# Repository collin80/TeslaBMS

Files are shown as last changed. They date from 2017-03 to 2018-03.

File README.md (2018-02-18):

Arduino compatible project to interface with the BMS slave 
board on Tesla Model S modules.

The modules are daisy-chained together with a TTL interface.
The interface uses a Molex 15-97-5101 connector and runs at
612500 baud. This can be a difficult baud rate to match with
arduino compatible processors. The Arduino Due and Teensy
3.5/3.6 boards are confirmed to be able to generate a suitably
close baud rate. The factory wiring to each module is comprised
of two sets of 5 differently colored wires:

* Red = 5V input to the module
* Green = Gnd for power and signal
* Gray = Fault output
* Yellow = UART Wire
* Blue = UART Wire

The fault output is active low. Use your own pull up to the fault line and if the line is pulled low then a fault has occurred.

Here is a PDF that explains how the wiring between modules and the master board is supposed to be:
https://cdn.hackaday.io/files/10098432032832/wiring.pdf

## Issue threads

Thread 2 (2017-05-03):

EEProm settings

tomdebree, 2017-05-03:
I need to rewrite the serial console to remove the references to the EEProm library because it is not part of a teensy. But great libraries so far, will see about now creating a bms master based on these libraries.

tomdebree, 2017-05-03:
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

collin80, 2017-05-03:
I had previously ported the GVRET firmware to Teensy so I ran into this same situation. The Teensy does have EEPROM it's just a different library. You can look at https://github.com/collin80/TeensyRET to see what I did.

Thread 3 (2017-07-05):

We are building a Tesla Powered car

jjwallace, 2017-07-05:
Hello, we are building an electric power car.  Which other boards have you tested on?  What would you suggest for a high-quality board?  I want to try interfacing with Tesla batteries this next week.

collin80, 2017-07-07:
Well, I've tested using an Arduino Due and a Teensy 3.6. I don't have experience outside those too. I did test a breadboard design with both of them so a purpose built board is not 100% necessary, just nice to have. There are a few things to keep in mind when searching for a solution to interface to the Tesla BMS sub-boards:

1. They're 5V so if you use a 2.5 or 3.3v board you will need level shifters. Both boards I used are 3.3v so I used logic AND gates as level buffers.
2. The baud rate is 612500. Slow processors will either not be able to generate this high of a baud rate or will not be able to generate this exact baud rate properly. 612500 does not exactly divide into the clock rate of most processors. The processor on the Tesla main board is 24.5MHz which is how they generate such a screwy rate. Both the Due and Teensy can generate a suitably close baud rate. The Due has an 84Mhz clock and 84Mhz / 137 = 613138 baud which is close enough to work. Some processors do not have such free baud divisors. Technically 16Mhz / 26 would probably work though.
3. A thousand amps tends to generate a lot of EMF so even if you didn't need logic buffers you might be best off using them as well as inductors and other noise cancelling devices. Battery packs are a noisy place to store electronics.

jjwallace, 2017-07-18:
Very interesting, this is great!

jorakarandas, 2017-10-23:
Hey Collin! Thanks for your contribution to the community! All the diy-ers appreciate it a lot.

 I encountered an issue with the Arduino Due and the Tesla BMS rev 2 and rev 3 boards. Arduino is sending the messages, but the boards don't respond back (from hardware point of view everything is fine, added lvl shifters).  Have tried 1 by 1 about 7 boards and another 8 which I installed in my car already in a daisy chain configuration as described by you.

What problems have you encountered during set up phase? Did the config work right out of the box? Was anything necessary from your side to make it work?
Thank you!!
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

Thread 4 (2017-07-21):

Jumping voltage Measurements

tomdebree, 2017-07-21:
I am currently working on using the data read from the slave to control charging I noticed there is quite a jump in values. The jumps are around 0.05V, currently using a high level timer to reset once a certain threshold is past.
Collin, did you notice the jumping of values too or is it possible to introduce a smoothing function over the values per cell?

collin80, 2017-07-23:
The resolution of the readings is a lot finer than 0.05v but if you're talking about full pack voltage then I suppose it is possible that 12 cells in series could add up to that much fluctuation. I hadn't noticed a constant 0.05 fluctuation but I suppose it does seem like the value wanders around a little bit.  It's certainly possible to introduce a layer of smoothing over the values. You could, for instance, take the previous 10 readings and average them. If you do this every 1 second then you'll get an average over the past 10 seconds. That might be OK for what you're doing or it might not. You can always read more rapidly and then average. If you need a 1 second value then you could read 8 per second and average over the 8. I don't know that such a thing will get added to this code base as it is meant mostly as a starting point for other projects and not as the absolute final code.

tomdebree, 2017-07-23:
I am using the commands:
bms.getAllVoltTemp();
bms.printPackDetails();

The values which are jumping are the cell voltages. these get put out roughly every 550ms

Attached a log from running these, all be it with some extra code to control charging.
         
[Tesla BMS voltage log.txt](https://github.com/collin80/TeslaBMS/files/1168440/Tesla.BMS.voltage.log.txt)

collin80, 2017-07-23:
Yes, I'm seeing it in your logs. It does appear to be about 0.05v. I'm thinking that it must be coming directly from the Tesla BMS module. I'd guess that their master board averages the voltages over multiple readings to make it more steady. Apparently the same thing will have to happen here. Sample more quickly and average the result. I'll try to do some more testing of this as well.

tomdebree, 2017-07-23:
If you can let me know how steady your readings are, I want to be sure it is not a wiring issue or something like that on my end.

collin80, 2017-07-25:
My readings are stable to within about 4 millivolts which seems to be a lot more stability that you're seeing.
I've attached a log from my pack. You can see that it sometimes fluctuates a little but, in general, readings are more stable than you're seeing. Perhaps your voltage source is shaky or you're picking up noise or your BMS modules are damaged. I can't tell for sure. But, hopefully having this baseline log file helps.

[TeslaBMS_Log.txt](https://github.com/collin80/TeslaBMS/files/1171632/TeslaBMS_Log.txt)

tomdebree, 2017-07-25:
Could you please test with turning the balancing function on?

tomdebree, 2017-07-25:
I can confirm it is indeed due to the balancing. Time to add another state to my state machine then.

Closed 2017-07-25.

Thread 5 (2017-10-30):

Tesla BMS reverse engineering

Pagode, 2017-10-30:
Hello collin80,

I am currently trying to connect Arduino Due with one Tesla Battery Package as part of a project for my study.
The Arduino is sending its messages but can't find the Tesla board.
I am also not sure how to wire the fault output you described in your hackaday project.
Hopefully you can give me any advice so that I can get further.

I am looking forward to hearing from you!

Reply:
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

Wiring:
red = 5V (Pin 1)
green = Ground (Pin 3)
yellow = TX (Pin 2)
white = RX (Pin 9)
black = fault (Pin 6)
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

jorakarandas, 2017-10-30:
Hi Pagode,

You shouldnt connect directly the boards to arduino due. Grab a 5v to 3.3v
level shifter, like 74ahc1g08.

Tell us your progress after that.

Good luck,
J

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

danfador, 2018-06-10:
Hello, @jorakarandas do you succeeded with tesla BMS and Arduino, I have two model s module and I get an Arduino Due  + Molex connector, what else I have to boy to comunicate with Tesla BMS?

One more question, without any external connection does testa BMS balance the cells ore not?

Thank you!

bstarr119, 2018-07-10:
Good Evening All,

I am having similar troubles as the original poster, unfortunately I cannot upload pictures from the mobile site. I have incorporated a level shifter with the due so that I do not over volt the tx rx ports. I will need to figure out something new to try but I am running low on ideas as I am new to CANbus and due ^^

NiallDarwin, 2019-08-21:
Hi @jorakarandas thanks for your suggestion of the level shifter. Please can you read this and let me know if I've understood correctly:
The ESP32 is a 3.3V chip & board so 5V could damage it.
The Tesla BMS boards are 5V.
This means that the Tesla board's Tx & Rx will be running at (up to) 5V and can therefore damage the ESP32. So using a level shifter means you can transmit the signal but drop voltage.
If all this is right I've got another question: Does the shifter cope with the baud rate OK? Is this a specification I need to look for when choosing a board?
Thank you :)

collin80, 2019-08-21:
Yes, the Tesla hardware runs at 5V but an Arduino Due or an ESP32 run at 3.3v instead. So you need a level shifter to go back and forth between the two voltage levels. What you need is a level shifter that can go fast enough. You have the baud rate of the Tesla hardware (625000) so what you need is a level shifter that can handle 1MHz digital signals. Cheaper shifters probably won't. But, plenty of options exist. And, in a pinch perhaps you've already got AND logic chips. Just feed the input to both inputs to the AND gate and output at the proper voltage. Logic gate chips tend to be plenty fast enough. You just have to make sure that the chips you're using will trigger at 3.3 and 5v even if the inputs are technically higher in voltage than the V+ rail on the chip.

NiallDarwin, 2019-08-21:
Thank you.

On Thu, Aug 22, 2019 at 11:07 AM Collin Kidder <notifications@github.com>
wrote:

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

--
Niall
NZ cell +64 221 275 438

NiallDarwin, 2019-08-24:
So I've now got  bi-directional board very like [this sparkfun offering](https://learn.sparkfun.com/tutorials/bi-directional-logic-level-converter-hookup-guide/all) and have made something happen. Unfortunately it seems I'm only transmitting not receiving-see screenshot. Two things I'm not sure of* are:
1/ I'm getting my 5V from the 5V pin of the Due. It's getting it from my laptop. My meter shows about 4.9V which I'd expect to be enough. Thoughts?
2/ Does the shifter need any pull up/down on any of the inputs or outputs?
If you want to see the rig, [here's a little video](https://youtu.be/c_d3D_629mw).
Thanks :)
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
*Lots actually but these are the relevant ones ;)

wizkid057, 2019-08-29:
Was linked here by a friend.  I haven't really followed this project, as I developed my own software/hardware to run the BMBs quite a while back (I actually just reflash the 8051 using Tesla's own update protocol, reverse engineered, and run my own code there.)

Anyway, the digital isolator used between the BMS side and the external connector can operate at 2.5V to 5.5V... and can essentially act as a level shifter on its own.  Just power the external side from whatever voltage in that range would be useful to you.  The filtering before the isolator is geared towards 5V operation, and this is the voltage Tesla uses for the bus... but definitely not a solid requirement.  It'll give a few tenths of a volt loss most likely, but shouldn't drop things below the 2.5V minimum at 3.3V supply.

In fact, I'm actually currently running my own home setup with 36 of these in a chain, and it's running at 3.3V directly off of my board's 3.3V regulator (repurposed the board from another project... will eventually use 5V).  Realtime view: https://wk057.solar/bms.php

All of that said, I'm unsure what the benefit of level shifter would be exactly, unless the 3.3V rail isn't strong enough to provide the few mA per board needed to run the isolators.  You should just be able to power the whole thing from 3.3V and be done with it.  The BMB won't know any differently, since the isolated side is still powered by 5V.

collin80, 2019-08-29:
I'm sure you're right. We never investigated the situation that much. We saw that the Tesla main board uses 5v so we kept using that voltage and just added cheap AND gates to shift the signal level. But, it's good to know that this is not strictly necessary. So I suppose everyone else might as well just plain power it with 3.3v and be done.

BobbyBleacher, 2019-08-29:
Well, Niall is getting more than me out of it. When I start up it tells me starting up and factory settings reset, but how do I actually retrieve any useful data now that I'm connected?

BobbyBleacher, 2019-09-01:
Disregard, I've got this all connected, powered up, and operating.,The boards just aren't being recognized by the Due for some reason. I've tried the tx/rx pins as well as the cantx/rx with no success.

KeithMcdorman, 2019-09-02:
Worth noting that if you hooked up the due to 5v signals your signal pins may be toast. The due is not 5v tolerant. Been there done that.

BobbyBleacher, 2019-09-02:
Signal pins are still outputting 3.3v

NiallDarwin, 2019-09-21:
Alrighty, I made it work!
IT WORKS :)
The problem was simple. I was using the wrong serial pins on the Arduino. If you look closely there's three TX/RX ports. I'd gone in on the 0 pair but the board was using the 1s. Hopefully this helps.
We also found that as per lots of advice here the Tesla boards work fine on the 3.3V of the Arduino so no need for the level shifter.
To diagnose this a friend came over and brought his logic analyser. This enabled us to see what the various channels were doing and was much, much better than just blindly trying different leads in different pins. They're NZ$18 here in NZ so probably about US$10 and worth at least 100x more!

Summary of what works for me on my 2016 BMS boards:
Run Tesla boards on 3.3V from Arduino
Use RX1/TX1 pins
No need for level shifter
Baud Rate: 631578 (Haven't tried if this is necessarily the only one but it does work for me)

Thanks Collin for writing and informally supporting this stuff. Thanks everyone else for their support.
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
NiallDarwin, 2019-09-25:
I reckon this can be marked as closed now?

sogorman, 2019-09-28:
Wk057 (been following your work for a while, have chatted with you a few times ago about 5 years ago, big fan), @collin80 , and @NiallDarwin thanks for all the hard work on this project. I am trying to get my arduino to interface with the Tesla BMS and have not had much luck. I have tried running at both 612500 and 617647 baud rate with no response from the board.

I took @wizkid057 advice and am running the board at 3.3V off the arduino header as to not require level shifting on the serial bus.

One question for the three of you.... does the board need to be powered by the pack as well? not sure if the 6S leads from the cells power and subsystem on the module.

I added some debug code to the setup function but here is all I am getting in the serial debugger.

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

I am using Serial1 in config.h and the BMS is connected to RX1, and TX1 on the arduino.

Here are some pics of my test bench...

Anything jump out at you guys?

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

collin80, 2019-09-28:
As WK057 said, the power you give the board is powering the isolation chip. So, you can power that chip with 3.3 or 5v but it was meant for 5V so it probably works best with 5V if you can swing it. But, the BMS side is powered by the cells themselves. Ordinarily the current draw is quite low and everything wakes up when you send it traffic. But, you do need power at the cells in order for the 8051 processor and BMS chip to operate. So, that is your biggest hurdle.

NiallDarwin, 2019-09-29:
@sogorman Yes, the boards need to get power from the Tesla batteries. I've edited my summary above to include this important piece of info. You didn't miss it previously ;)

sogorman, 2019-10-03:
@NiallDarwin appreciate it and thanks to the entire group... she is now talking!

Nzo-Po1, 2023-07-04:
Bonjour @collin80 ,
J'ai besoin de ton aide concernant le code que tu utilises afin d'afficher la tension et la température du pack de batterie. En effet, j'utilise comme support la carte arduino DUE R3 qui fonctionne en 3,3V. Voila le code que j'utilise :
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

Mes principales questions porte surtout sur le code car je ne sais pas où trouver la bilbliothèque SerialConsole.h. Je n'ai pas un niveau élevé en programmation mais il semble que ce soit une bibliothèque que tu ai fais toi même. Sais-tu où puis-je la trouver et comment l'ajouter aux bibliothèques de la carte ?
De plus, je ne comprends pas comment faire fonctionner cette ligne : SerialSpecialInit(USART0, 612500).
Suis-je censé ajouter une bibliothèque ou bien rajouter autre chose ? Pour être honnête, je ne sais pas à quoi corespond non plus les fonctions que tu as écrites comme "BMSModuleManager.h" ou bien "Logger.h". Tu les a écris en JAVA mais la carte Arduino n'et programmable qu'en C++ il me semble, c'est pourquoi je me sens un peu perdu :(

De plus, voici le câblage effectué, j'ai suivi les instructions que tu avais donné.
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

Merci d'avance de ton aide précieuse. ;)

collin80, 2023-07-05:
Well, of all the languages I can read, French is not one! ;) But, thankfully Google Translate exists. I believe you haven't properly downloaded all of the source code for TeslaBMS. The function "SerialSpecialInit" is found right in TeslaBMS.ino up near the top. The SerialConsole and other missing files are also right here in the repo so try downloading it all again. Lastly, make sure you have selected Arduino Due (Native Port) as the board you are compiling for. It's really easy to accidentally try to compile for a different board but this will not work.

Nzo-Po1, 2023-07-06:
Sorry @collin80, I forgot to translate ;) Indeed, I saw that I forgot to download all the libraries I need like due_can, wireEEprom ... So for now, the code compiles fine but I don't have the text in the serial monitor that I'm supposed to have ... Do you think you know why? I'll keep looking.
Anyway, thanks for your work, it helps me a lot :+1:

kveksen, 2023-09-23:
The tesla moduleboard is blinking but I just got this and nothing more.
What did I do wrong?

13:42:34.530 -> Starting up!
13:42:34.530 -> Started serial interface to BMS.
13:42:35.832 -> Resetting to factory defaults

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

Vistr169, 2025-01-24:
Hello @collin80,
Thank you so much for this programm, it work very well for old types of Tesla Batteries.
One question. Is it possible to make some changes at this code, that it work correct with Tesla Batteries 75kw, 100kw 2016-2021?
We had Tesla Model S Long Range 2021 with broken battery. Programm comunicate with BMB but not correct, and commands not the same.

evcepi, 2025-03-18:
Hi Enginers
i have problem with programing Arunio Due
somebody want help me private i pay for help?
I need to programing i need tool for see voltage cells and everthing?
Thank you

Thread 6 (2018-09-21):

closing the main contactors inside the Tesla model-S battpack

TLS1000, 2018-09-21:
Hi, I'm trying to use the kit from EVTV, for using the complete model-S battery 'as is' without opening it.
Your code does a great job reading all cell voltages and so. BUT: the main internal contactors that connect the internal batteries to the power port of the pack don't want to close. Are these main contactors controlled via code or is it purely hardware?

collin80, 2018-09-25:
You'll have to ask Jack directly about that. I wasn't really involved in the whole pack control system. This project you've submitted the issue to is for controlling the modules inside the pack directly.

TLS1000, 2018-09-25:
hmm...the collaboration with Jack is not working out :-) . We will try the kit on a second model-S battery to be sure, but I'm afraid we'll have to take the battery apart and go for 48V-setup.

Closed 2018-09-25.

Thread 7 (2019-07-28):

ESP32 due code

martiinezz, 2019-07-28:
Collin - great work with the code. My question is if you're going to port this code to the latest ESP32 based board?

Thanks.

BobbyBleacher, 2019-09-16:
Is that why none of us can get this working? We've got a newer version of the board this was written for?

collin80, 2019-09-16:
Well, I did in fact port it over to the ESP32 for a project but that project didn't actually end up open source so it isn't on here. But, rest assured, it can work on an ESP32. I think really the biggest change to compile on an ESP32 is that it has no USB based serial so all the status output needs to go to a normal serial port instead and the serial port to communicate with the BMS slaves is initialized differently.

Here's some quick advice for setting up the serial port to the tesla hardware:
HardwareSerial Serial2(1); //define second serial port for Tesla BMS board
Serial2.begin(BMS_BAUD, SERIAL_8N1, 4, 2); //rx pin is 4, tx pin is 2

Obviously BMS_BAUD should be one of the speeds, 612500 being a common one. There's a slightly faster one for newer Tesla hardware, 631578. I think we had better luck just using 631578 all the time. I don't think the ESP32 can quite generate that exact rate but it gets close enough.

So, no, I don't believe the ESP32 is available anywhere but really you just redirect all serial console output to Serial and all BMS traffic to Serial2 - initialized as above.

BobbyBleacher, 2019-09-17:
I'm staring at this code trying to figure out how to make it do just that. I'm mostly unfamiliar with all of this, so most of what I'm trying results in failure to compile or something I don't even want to go try after it does compile because it simply doesn't make sense.

So the Due, which does have SerialUSB, needs to NOT use that and initialize two separate serials (looks like HardwareSerial doesn't need the initialization code you put there), and the Serial2.begin statement provided has two too many arguments.

 What was this originally written for if not the Due?

collin80, 2019-09-17:
No, the code as provided should have worked on the Due. That's what it was written for. I was talking about the ESP32. In order to compile for ESP32 you need the special serial init I posted and you can't use SerialUSB since ESP32 has no SerialUSB - Due does.

BobbyBleacher, 2019-09-17:
Oh... Yes, it definitely doesn't work on the Due as noted in Niall's video. I'm getting the same results as him. LPG on the Tesla forums also had the same experience.
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

collin80, 2019-09-17:
What is interesting about your picture is that you are getting the exact same bytes returning as you sent. That isn't really what it should be doing. The Tesla module should be catching the bytes that you send and be broadcasting but with changes. 7F is a broadcast and 0 if I remember correctly is used to number the modules automatically. It shouldn't be directly passing those bytes back. Something seems odd there. You should make sure you don't have a direct loop between TX and RX. Does your first tesla module in line have LEDs flashing on the board when it gets traffic? Near the bottom you should see flashing upon traffic. This can help to verify that it is receiving data bytes.

BobbyBleacher, 2019-09-17:
The light on the BMB comes on only during power up, but that's it. If you're interested in troubleshooting (and I definitely am) we can chat elsewhere. I have Whatsapp, discord, slack, etc.

collin80, 2019-09-17:
Yeah, sounds like you've got some major comm issues then. Every single time the code tries to send something to the Tesla modules you should get a flash of light at the LED. So, things are not getting through properly. I have slack and I think discord. We can move this out of the github issues and to email, then perhaps to one of the other services from there. kidderc at google's email service.

CZal, 2019-09-17:
Code works for me... I think there is an issue with your wiring to the modules....

Btw, Great work Colin...

BobbyBleacher, 2019-09-17:
Care to share some knowledge? There are several of us that can't get it working and it does not appear to be the wiring. Would love to see photos/videos of your setup.

martiinezz, 2020-01-19:
@BobbyBleacher So what was your issue?

twanek, 2021-02-19:
hello!

thank you sharing this great work! i also would like to port this code to esp32. anyone can help me, where to start? unfortunately, i do not have a due, so i have to begin directly with the esp32...

best regards!

collin80, 2021-02-24:
I gave the relevant advice up above. I don't know for sure what else you'd want to know. On the ESP32 your user facing output should be sent to Serial instead of SerialUSB and you need to initialize the second serial port that talks to the modules as I specified above. Other than that, both chips support Arduino so once you install the Arduino support for ESP32 you should only have to make those two changes and it should work.

MohamedGaberZidan, 2022-12-05:
> I gave the relevant advice up above. I don't know for sure what else you'd want to know. On the ESP32 your user facing output should be sent to Serial instead of SerialUSB and you need to initialize the second serial port that talks to the modules as I specified above. Other than that, both chips support Arduino so once you install the Arduino support for ESP32 you should only have to make those two changes and it should work.

Hello,
when I did this I had some problems with due wire library, could you tell me what I should do?. Thanks in advance.
best regards.

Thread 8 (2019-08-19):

balancing?

Energyfuzzi, 2019-08-19:
Hi, great job!
I try to implement it on a Volkswagen Beetle with 5 Tesla Bricks, looks good!
While checking the balancing, I found that there is something strange inside your code:
You start balancing at 3.9V, and stop when the cellVoltage is below this Voltage minus a balancing hysteresis.
There are 2 problems I see, because "balancing(i)" seems to mean: burn the energy at the resistors at cell(i)!
1) So the Resistors from each cell burn energy every time the Voltage is higher than 3.9 V unless it is below 3.86V, even if the voltage should be at 4.1V.
2) During balancing the Voltagemeasurement does not work properly, because of the structure of the electronic.

I would suggest starting balancing, if the difference to the neighbour cell is to high, maybe via the difference between avgCellVoltage and cellVoltage(i), or just by comparing, and a minimum voltage is guaranteed (as already done).
Then the balancing should last 2-5 min, should stop, then after a short time start the measurement and the balancing again.
What do you think?

collin80, 2019-08-20:
You're pretty much right all the way around. The balancing stuff found in the public code is only to be used as an example of how one might be able to turn on balancing. It certainly isn't a very good algorithm. So, yes, I would recommend you implement something better.

Energyfuzzi, 2019-08-20:
thanks, I´ll change it for my needs on the Volkswagen beetle.
And by the way: thanks once more for finding out, how to communicate with the original TeslaBrickElectronic. It really helps to use the original Brick instead of using a custom BMS!
Has there been something new about the communication in the last 1-2 years (since you posted the code?) All the best from Austria!

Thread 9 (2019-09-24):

BMS board revisions? What should I look for?

baysinger, 2019-09-24:
If I were to purchase a module, is there any particular BMS revisions I should look for? Or are all the Model S modules compatible with this project?

baysinger, 2019-10-18:
To partially answer my own question, it does indeed work with whatever this is:

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

collin80, 2019-10-18:
Sorry, I meant to answer this long ago but completely forgot about it. Any of the Model S battery revisions should work. It appeared that they changed serial speed between revisions but only slightly and the code can support both. To my knowledge there are two main revisions of the BMS boards. One is larger than the other. But, either way they speak the same protocol and the only communication difference is a slight speed change. The old ones were 612500 and the new one something like 631000 (don't remember exactly). Other than that they work the same.

baysinger, 2019-10-22:
Thanks. BTW, I left the baud rate alone (617647) and it's working fine. Not sure where that number comes from, though. Close enough to either speed to work, maybe?

Closed 2019-10-22.

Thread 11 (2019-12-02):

Can't get more than 14 modules to register

BobbyBleacher, 2019-12-02:
And it looks like the code is right. It should theoretically go to 62 without any issues. Any else experience anything similar?

collin80, 2019-12-03:
Yes, the theory is 62 as that's how many addresses can be assigned. I'm not aware of anyone getting that carried away though. However, EVTV makes a 100Kw solar power system so it has to be using more than 14 modules. My first guess, knowing nothing of your set up, is that you might perhaps need more power. In the car the modules were powered by 5V. You can technically power them at 3.3V too but either way you need sufficient power. If you setup does not include a fairly powerful DC power source then you could run into issues. I doubt that an Arduino Due or other development board has enough power output to run a ton of modules. I think we tested up to 8 or so with just the development board but much over that you need a dedicated DC/DC power supply. So, let me know if you're using a sufficient DC/DC converter and if so we'd have to look elsewhere for the problem.

BobbyBleacher, 2019-12-03:
I'll go try the 5V side. It's true I've been using only the 3.3v output from the Due.

BobbyBleacher, 2019-12-03:
Ehh, unfortunately, no. Anything more than 14 modules and I get zero to show up.

collin80, 2019-12-03:
The Due is not a world renowned source of DC voltage. ;) Can you try with a benchtop supply or some sort of voltage supply that can provide 1A at 5V? Maybe a wall adapter? At some point you will overcome the current sourcing capacity of the Due and then you'll get weird problems. I can't say for 100% sure that's your problem but it could be ruled out with a separate supply.

BobbyBleacher, 2019-12-03:
I got it! It was an misunderstanding my part, actually. Your diagram is a big help, but the Tx/Rx lines from the left half of the connector go into the right half of the next connector. I had wired them straight over (I was adding these two modules to a factory wiring harness). It all works now. I'll close it.

Thanks again for the software, Collin. I've edited it quite a bit now to mimic the EVTV setup and it seems to be working fairly well. Check out my fork some time!

Closed 2019-12-03.

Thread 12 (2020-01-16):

Can't compile

taraskarpuk, 2020-01-16:
`Documents/Arduino/libraries/due_can-master/src/due_wire.h:25:25: fatal error: include/twi.h: No such file or directory`

Anybody know how to solve issue?

collin80, 2020-01-16:
Are you sure you're compiling for the Arduino Due? It's super easy to accidentally select the wrong board. The Arduino IDE is not super great at letting you know that you've got it set wrong.

taraskarpuk, 2020-01-17:
Yes, builded for Due it's fine. But i have fail at startup
`Started serial interface to BMS.
Resting to factory defaults`

collin80, 2020-01-17:
The Arduino Due does not have EEPROM. That has to be added by whatever shield you're using (if you had one). Otherwise it will try to access EEPROM and not find one and freeze for a while as it tries to access the nonexistent chip. That's why it says it is resetting to factory defaults. It can't find valid EEPROM settings so it tries to write them to EEPROM to initialize. It won't be able to do so and so it freezes for a long time. The solution is to either add an EEPROM chip on the I2C pins of the Due or comment out all the places where it tries to use it and just leave things hard coded. That's what most people do.

taraskarpuk, 2020-01-17:
what baud rate is required for 1028578-01-C REV03 and shoud be yellow and blue shorted?

taraskarpuk, 2020-01-17:
`19:25:22.079 -> Sending: 7F 20 FF 7D
19:25:22.079 -> Reply: 7F 20 FF 7D
19:25:22.079 -> Sending: 7F 20 0 8E
19:25:22.079 -> Reply: 7F 20 0 8E
19:25:22.079 -> Sending: 7F 21 FF 68
19:25:22.079 -> Reply: 7F 21 FF 68
19:25:22.079 -> Sending: 7F 21 0 9B
19:25:22.079 -> Reply: 7F 21 0 9B
`

taraskarpuk, 2020-01-18:
Successfully connected, problem was in baud rate

Closed 2020-01-18.

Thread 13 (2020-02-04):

BMS stops responding and must be rebooted

BobbyBleacher, 2020-02-04:
A few times a day I've noticed my BMS will just stopped outputting any information and no longer responds to commands even though I can still use screen to get to serial interaction. I'm not sure if that is directly related to my fork specifically or if this happens in Collin's original code, but I can't figure out why or where to set some data logging to figure out how to fix whatever's broken. I'm guessing that maybe there's some sort of memory that's filling up that isn't properly being flushed. I keep it running non-stop.

The only fix currently is for me to send a reboot command to the pi powering it. Any help narrowing down the issue would be appreciated because this is otherwise a completely autonomous system.

collin80, 2020-02-04:
Well, there are lots of units out in the wild running with code based off of the code here so it seems likely that there isn't a problem with this code. However, I have not personally run this exact code for days on end. You might try tracking the results of queries to the BMS boards to see if there's something you can point your finger at. Maybe the comm is getting corrupted, maybe they really just aren't replying at all anymore, maybe the code isn't actually sending data to the BMS modules. So, you will probably need to add some instrumentation to bms.getAllVoltTemp() and the functions it calls.

Closed 2024-04-19.

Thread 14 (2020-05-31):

The problem with the code (arduino)

Bezzeb, 2020-05-31:
Good afternoon.
Thanks for the project and the work done.
I have a problem with the code for arduino.
I completely copied the code for arduino due,uploaded to the board
Connected arduino due to the tesla bms
Arduino due - level converter- tesla bms
+5 v                 HV                       Pin1
                          +4.7KOhm         Pin6
gnd                  GND                    Pin3
3,3v                  LV
TX                    Lv1                       Pin2
RX                    Lv2                       Pin9
The bms LED lights up when turned on, and then flashes briefly
on TX and RX 3.3 volts

And there are a few problems
1)In the serial monitor receives information only after the upload code to the board
when reconnecting, nothing is displayed
2)after upload code to the board all information stops at "Resetting to factory defaults"
14:54:00.247 -> Starting up!
14:54:00.247 -> Started serial interface to BMS.
14:54:01.516 -> Resetting to factory defaults

I understand this is the problem of arduino due ?
not tesla bms ?

collin80, 2020-06-02:
Did you try sending a ? with a line ending (that is, push ENTER after ? or have the Arduino Serial terminal send ? and tell it to use some sort of line ending). That will give you a menu where you can select what you want to do. If that's not working then something has locked up and we'd need to figure out where and why..

Bezzeb, 2020-06-16:
> Did you try sending a ? with a line ending (that is, push ENTER after ? or have the Arduino Serial terminal send ? and tell it to use some sort of line ending). That will give you a menu where you can select what you want to do. If that's not working then something has locked up and we'd need to figure out where and why..

Thank you so much
Everything works fine
Is it possible to get data on all battery cells? (voltage)

Closed 2020-06-28.

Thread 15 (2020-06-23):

Problem getting code to compile

ahrenswett, 2020-06-23:
@collin80 HI! First I want to say thank a ton for taking this on! Its invaluable and so glad I can use the existing board.

I am new to Arduino and C++ usually code in java so hopping you can help me get this going!
here is a link to the commit on my fork with the changes I made for my Due. [My commit](https://github.com/ahrenswett/TeslaBMS/commit/bddc6d23be85af160ee13dc2fdeb8958de1c6492)

I was able to get all the libraries you wrote included as that was first issue. Then I ran into this and changed from serial to USART that seemed to work or at least not error out
```
//Set to the proper port for your USB connection - SerialUSB on Due (Native) or Serial for Due (Programming) or Teensy
#define SERIALCONSOLE   Serial

//Define this to be the serial port the Tesla BMS modules are connected to.
//On the Due you need to use a USART port (Serial1, Serial2, Serial3) and update the call to serialSpecialInit if not Serial1
#define USART  Serial2
```
But now it is throwing an `error
```
In file included from sketch\BMSModule.cpp:3:0:
sketch\BMSUtil.h: In static member function 'static void BMSUtil::sendData(uint8_t*, uint8_t, bool)':
BMSUtil.h:37:16: error: request for member 'write' in '0', which is of non-class type 'int'
         SERIAL.write(addrByte);
                ^
```
Again thanks a ton for all your work!

ahrenswett, 2020-06-24:
Realized my error in changing to:
`#define USART  Serial2`
changed to
`#define SERIAL  Serial1`
then changed the call to serialSpecialInit in TeslaBMS to:
`serialSpecialInit(USART1, BMS_BAUD)`

Now top error has to do with `externa EEPROMSettings settings;`

ahrenswett, 2020-06-24:
now im having issues with due_wire. where do I find that?
```
// Include Atmel CMSIS driver
#include <include/twi.h>
```

collin80, 2020-06-24:
https://github.com/collin80/due_wire

ahrenswett, 2020-06-24:
> https://github.com/collin80/due_wire
got that :) but had some other issues after ide reverted to uno board
here are my errors now. really struggling with this :( I pushed my changes just in case you can take a look.
feels like i'm going in circles.

In file included from sketch\Logger.h:31:0,
                 from sketch\Logger.cpp:27:
sketch\config.h:10:0: warning: "SERIAL" redefined [enabled by default]
```
 #define SERIAL  Serial1
 ^
In file included from C:\Users\ahren\Documents\ArduinoData\packages\arduino\hardware\sam\1.6.12\cores\arduino/Arduino.h:44:0,
                 from sketch\Logger.h:30,
                 from sketch\Logger.cpp:27:
C:\Users\ahren\Documents\ArduinoData\packages\arduino\hardware\sam\1.6.12\cores\arduino/wiring_constants.h:43:0: note: this is the location of the previous definition
 #define SERIAL  0x0
 ^
```

ahrenswett, 2020-06-25:
> https://github.com/collin80/due_wire
Got it. is it normal to get red messages about redefining SERIAL and than have it compile?

collin80, 2020-06-25:
I don't seem to get that warning when compiling the code. I don't know where that's coming from. But, hopefully it works anyway.

ahrenswett, 2020-06-25:
> I don't seem to get that warning when compiling the code. I don't know where that's coming from. But, hopefully it works anyway.
Got It! notice the light flashing as i was checking ports looks like the pins on the end of my wires for my breadboard were to thin to give a good connection on the header to the arduino. wiggled a bit and now its golden! got the menu after typing ?

Closed 2020-06-25.

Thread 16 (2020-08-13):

Raspberry Pi instead of Arduino?

thezeroth, 2020-08-13:
What does it take to run this code on a Raspberry Pi instead of Arduino? Raspberry Pi runs off 5v DC and also has IO pins with 5v DC which seems to be the same voltage that the Tesla BMS is using.

collin80, 2020-08-13:
Really comm to the Tesla BMB boards is TTL serial at 5V. So, if you can connect the RPi over serial you should be set. The baud rate is quite odd but one has to presume that the RPi can generate it. There are other pins that have fault signals and such but what the BMB needs to work is power and serial. The other pins you can ignore if you want. Or, you can connect them, they're on/off digital signals.

pilotniq, 2024-03-10:
FWIW, I'm running a Raspberry Pi talking to the battery modules BMS boards over a serial port (on my electrified boat). My Javascript (node.js) code is here: https://github.com/pilotniq/MJoulnir/tree/main/RaspberryPi/software/bms

thezeroth, 2024-03-10:
@pilotniq thanks for sharing, I will look into your code,  I was thinking about making "Node Red" on a raspberry pi to talk to Tesla BMS, That can open many possibilities  like notification via MQTT,  integration with node red web user interface to show battery state on web widgets, logging battery data on a database like InfluxDB, then visualizing that data via Grafana, etc. Last time I checked there is a CAN addon for Node Red.
Can you please also share what type of hardware you are using to interface pi to CAN and what model of raspberry pi? How did you wire all battery modules to the pi? Would be great if you could provide pictures of your setup.

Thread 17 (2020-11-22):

Couldn't find a Board on the selected port.

49thdiver, 2020-11-22:
Greetings, I have tried to get this to go 3 or 4 times now with no success. I am not new to arduino programing but not an expert either. I have successfully built projects including can bus on uno, due & 2560 boards. I have done some can bus bridge work and am using ide 1.8.8
Your code complies and uploads via the native port, when the board is reset it can not find the serial port. The console on the programming port shows nothing. I do not have the Tesla BMB even connected. If I could get the "Starting up!" message I am sure I could debug the rest.
From what I read elsewhere this error message is as a result of something wrong with the sketch corrupting the serial I/O or possibly the libraries are not compatible.
If I reset communications and reset the board I can get the serial ports back and compile and load known working sketches.
I dumped the clone boards and have the original Arduino product still no joy.
Collin I know this project is kinda dated and you may not have time for it but I need help. I have two Tesla modules I would love to be able to use with this code for a solar project. I would not bother anyone unless I had run out of ideas, but now I am now desperate. Error file attached, perhaps there is an indication there of an incompatible library. Thank you in advance !!
[teslabms error.txt](https://github.com/collin80/TeslaBMS/files/5579051/teslabms.error.txt)

collin80, 2020-11-22:
Looking at the error file you sent, it appears you have your libraries all messed up. TeslaBMS should not be in the libraries folder. That's the main program and it should be found elsewhere, basically anywhere but the libraries folder. It looks like maybe you have due_wire and wire_eeprom in a folder called kidder which I suppose isn't a problem so much about the folder name. But, those are two separate libraries and you seem to have them in the same folder. That probably isn't really the problem either but it isn't really "correct." I think you might want to delete the libraries and start over. Download the actual libraries one at at time and put them in your libraries folder. Then put TeslaBMS somewhere else, say in your Documents folder, open it, and try compiling. I don't know why you are able to compile but it doesn't work when it has uploaded. But, I do hope that cleaning up your libraries might fix it.

49thdiver, 2020-11-22:
Thank you for your quick response, all I can say is "Remarkable". Last night  after posting my call for help I decided to get dramatic and set to clean up my libraries by removing all of the unnecessary folders. I then started to remark out major sections of the code and the includes to cut it down to something that at least created some output on the programming port console using Serial.print. At around midnight I was able to get output on the programming port but still noting on the "SERIALCONSOLE". 90% of the code was eliminated. Introducing line by line the #includes caused it to fail again.
Went to bed.
You email this morning was a welcome conformation I was on the right track, not sure how TeslaBMS got stuck in the library, that was a result of rebuilding 1/2 a dozen times and getting sloppy. So I set to implement your suggestions, significantly, removing duplicate can_due files, placing wire and eeprom in the own directories with appropriate names and moving TeslaBMS to the appropriate place in a sub-directory of my Arduino folder with all my other projects directories.
This has not completely resolved the situation but is significantly better. It Compiles and loads successfully, the only out put I can get however is via Serial.print.
Things to note are that the upload process now ends with the ide printing "Done uploading" on the status bar all the time and more significantly the Port on the Tools menus is correctly identified by name not just a port number, which never appeared to be correct, i.e. com15 not com16 where the correct named port is.
I am now working thru the code to determine why I am not getting any output on the "SERIALCONSOLE", I have been inserting "Serial.print" commands to step thru the code. The SerialConsole.h is included at the start.
I am not sure how the logger is supposed to work in the arduino world I have used a similar tool in the android environment, but I am only using the Arduino ide for this work so far.
I do have Atmel Studio 7 and an AVR that I am using for another ATxmega32C4 project but have not used it for any of my other arduino projects yet. Should I be using that and will it help to debug. I anticipate I will find my way thru this now thanks to your wisdom. If I am missing something else obvious please let me know. I have not looked at the "SerialConsole.h" or "Logger.h" files yet perhaps all will be revealed.

Thanks for taking the time to read thru my error log and point me in the right direction.
All the best to you, Peter

[Nov22_TeslaBMS_Log.txt](https://github.com/collin80/TeslaBMS/files/5580173/Nov22_TeslaBMS_Log.txt)

49thdiver, 2020-11-22:
AH ha, clearly should have looked at the config.h file associated with SerialConsole.h and Logger.h
I needed to change from the default "#define SERIALCONSOLE   SerialUSB" to "#define SERIALCONSOLE   Serial"
It appears to now be ready to connect to the batteries, I have the level converters and cabling ready to go.
Thanks, Still learning ............ after all these years ;).
Will close file after testing with batteries.
Thanks Collin.

49thdiver, 2020-11-24:
I have had some success, with good data coming over from the battery, however I am mostly I am getting bad data, back from the batteries. I have used baud rates between 608695, 612500, 617647and 631578 it all get s confusing but I think my good results were obtained at 612500 or 617647. It may be I am having some hardware issues but your software is for sure working. The key to getting it workings was cleaning up the library and changing the config.h file for my configuration. Thanks for you work in developing this and sharing it. It's your generosity and others that help people like me develop new idea's and project and in turn share what we have learned. Thank to everyone. I will close this comment and drop a note here when I get the hardware working.

evcepi, 2025-03-22:
Hello
Maybe help
I not

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

see voltages and cells?

Closed 2020-11-24.

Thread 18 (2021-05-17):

Tesla BMB heating

sagez400, 2021-05-17:
Hello Collin,
I am working on a college research project involving the use of Tesla Model S batteries.
Following the previous issues discussed, I was able to get the code working.

However, I ran into an issue of the boards heating up a lot (in the area between the cell connectors) when module information was being displayed to the serial monitor. Regardless, the data is still being read properly.

Setup:
Tesla Model S P100D battery modified for 48V
Two Tesla BMBs (one for cell group 0-5, and one for cell group 6-11)
Boards run on 5V from the Arduino Due, powered by each proper group of cells as mentioned above, and use RX1/TX1
Only one temperature sensor is connected since I am only using one module
Baudrate set at 631578

I'm not sure if the code or the 5V from the Due is a cause here.
Any suggestions as to where I could start troubleshooting the heating problem?

collin80, 2021-05-17:
Are you sure something isn't commanding balancing? That will heat up the cells.

sagez400, 2021-05-18:
I did not notice at first that the void loop function had an interval balancing command.
Heating issue is solved, thank you!

Closed 2021-05-18.

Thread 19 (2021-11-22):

Not documented

GusakIurii, 2021-11-22:
Can you please tell me where you can find the purpose of these inputs and outputs?
const int IN1 = 16; // input 1 - high active
const int IN2 = 17; // input 2- high active
const int OUT1 = 20; // output 1 - high active
const int OUT2 = 21; // output 1 - high active
const int OUT3 = 22; // output 1 - high active
const int OUT4 = 23; // output 1 - high active
const int OUT5 = 3; // output 1 - high active
const int OUT6 = 4; // output 1 - high active
const int FUEL = 5; // PWM signal of the fuel level sensor

Maybe there is an electrical circuit somewhere?

Closed 2021-11-23.

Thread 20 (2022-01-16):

ERROR: Invalid module response

Bernhard1023, 2022-01-16:
I have 4 Tesla Battery Packs (Model S 2012), which I tried to read out the BMS with an Arduino Due and a level shifter.
(https://www.az-delivery.de/products/logiklevel-wandler-3-3v-5v?variant=18282761715808)
I always get this error, and I don't know how to proceed further...
The error:
5447 - ERROR: Invalid module response received for module 1  len: 3   crc: 8   calc: 45
6448 - ERROR: Invalid module response received for module 1  len: 3   crc: 8   calc: 45
7449 - ERROR: Invalid module response received for module 1  len: 2   crc: 8   calc: 14
8450 - ERROR: Invalid module response received for module 1  len: 3   crc: 8   calc: 45
9451 - ERROR: Invalid module response received for module 1  len: 3   crc: 8   calc: 45
...
This occurs at all 4 modules.
Is the communication broken, or does it even happen?
Where is the best point to search for the problem?

collin80, 2022-01-17:
Hmmm, well, the fact that the CRC calculation is showing a mismatch probably means that the traffic is being messed up on the wire. Sometimes level shifters can be problematic. On the "official" EVTV board we used AND gates as a buffer. Alsom afterward it became known that you do not need to level shift at all. The Tesla modules work fine at 3.3v so if you power them via 3.3v you can directly interface them to the Due without any additional hardware in between. This is probably the easiest path forward.

Bernhard1023, 2022-01-18:
Thanks for the fast response.
I removed the level shifter and tried it out with the 3.3v.
Right now my serial output looks like the following:

Starting up!
Started serial interface to BMS.
Resetting to factory defaults

If I unplug the Tx wire, I get similar errors as described before, just with a lot of zeros, which makes sense for me.
Why do I get no output? (I use the Programming Port on the due and changed the line in the config.h to "Serial" as  described.)

It seems like the software is entering the main loop because the LED on the Tesla Module is flashing every second, which should be the indication for a data transfer, or at least the try to transfer.

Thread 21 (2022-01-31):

BMS module reverting to fault state?

Maymur8, 2022-01-31:
Hey everyone, I'm hooked up to a single module and keep seeing the error below

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

Has anyone seen this error before?
I've tried this across a single BMS module in a battery, isolated and separated from a battery, and attached to a custom battery. In all of these cases I get this error + the LED on the module is not lighting up (Which I was able to do running the CANSkeleton program)

Due to the consistency of the errors across different cases I'm thinking there's something wrong with my setup - has anyone else seen this or know of a fix?

Other sidenote is I'm running this on an EVTVDue

Let me know, thanks!

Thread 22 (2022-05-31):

Tesla BMS test

KGog, 2022-05-31:
Hello
After uplode I am getting such error mesage Arduino: 1.8.19 (Windows 10), Board: "Arduino Mega or Mega 2560, ATmega2560 (Mega 2560)"

In file included from C:\Users\kgogoladze\Documents\Arduino\Tesla_BMS\BMSModuleManager.cpp:2:0:

BMSModuleManager.h:4:10: fatal error: due_can.h: No such file or directory

 #include <due_can.h>

          ^~~~~~~~~~~

compilation terminated.

exit status 1

due_can.h: No such file or directory

This report would have more information with
"Show verbose output during compilation"
option enabled in File -> Preferences.

collin80, 2022-05-31:
That's because you are compiling for an ATMEGA board while the code is meant to be compiled for the Arduino Due. It's a completely different processor. You will also need the due_can library so ensure you've installed that as well. I wrote the due_can library so you can find it in my repos here.

KGog, 2022-06-20:
Hello,
Now I tried with the DUE board but without any success, the same error is presented. Could you please indicate where I can find due_can.h file?
Thank you in advance
Looking forward to your reply

In file included from C:\Users\kgogoladze\Documents\Arduino\Tesla_BMS\BMSModuleManager.cpp:2:0:
C:\Users\kgogoladze\Documents\Arduino\Tesla_BMS\BMSModuleManager.h:4:21: fatal error: due_can.h: No such file or directory
 #include <due_can.h>
                     ^
compilation terminated.

Compilation error: exit status 1

KGog, 2022-07-30:
Hello,
I think I have success I have run your code
Could you please check atteched log file?
[LOG.txt](https://github.com/collin80/TeslaBMS/files/9227142/LOG.txt)

collin80, 2022-07-31:
That looks like a successful build to me

ViktorGys, 2025-04-10:
Здраствуйте! Такая же проблема.
 due_can.h: Нет такого файла или каталога.
Что делать?

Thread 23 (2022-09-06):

Not sure how to use it with arduino due

yashindmitry, 2022-09-06:
Hi
Downloaded and deployed your project with dependencies. Didn't change any settings. Compilation successful, uploaded. The orange LED on the board is on and nothing is written to the port monitoring. What is the problem?
P.S. Haven't connected to bmb yet.

yashindmitry, 2022-09-14:
I'm sorry, the problem was in a non-working arduino board.

Closed 2022-09-14.

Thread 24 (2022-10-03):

Native USB and reset button goes dead

daimlerman, 2022-10-03:
Hello,
I am working on a project were i want to talk to some older tesla battery modules for  a home battery. Battery module are out of  a MB B class and sketch is uploaded to a Arduino Due
My sketch is somehow disabling the reset button and the native USB port. the only way to get it back is to erase the Due. Once erased the USB port is recognized by the PC right away and the reset button functions again.
I configured the config.h to #define SERIALCONSOLE   SerialUSB.
The sketch compiles with out error and a second Due acts the same way.
What other setting am I missing?

Many thanks

twanek, 2022-12-02:
Hey!

If it is still relevant, try to use the other micro usb port, not the native. To switch, in the code just edit `#define SERIALCONSOLE SerialUSB` to `#define SERIALCONSOLE Serial`, then in the IDE also select programming port.

daimlerman, 2022-12-04:
Thank you Twanek for responding!
I had figured this out and fix by reorganizing the depository structure, much like a post from the closed issues section.
Besides using the programming port, i have yet to get a reliable communications going. I reports the wrong numbers of modules and the voltages are all over the map.
Has you or anyone else nailed the baud rate down for the B-class module?

twanek, 2022-12-05:
Are you sure your module is 6s and not 7s? For me, with the 7s module (Merc C class), it has issue correctly identifying the number of modules, and the voltages too. See my opened issue here: https://github.com/collin80/TeslaBMS/issues/26

As for the baud rate, the C class module seemed to work with most of the baud rates specified in the sketch. Did you tried the 631578 baud?

collin80, 2022-12-05:
I've got to be honest, I've never heard of a system using this chip that has 7S modules instead of 6S. So, this is new to me. However, this much I can tell you - the BMS chip used supports 3 to 6 cells. I'm sure you can see where this would be problematic since it cannot read 7 cells. The only viable solution is thus to have 3 cells on one chip and 4 on a second chip. This makes each module look like 2 modules to the TeslaBMS code because there literally are two chips it is talking to. You're going to have some trouble here. In theory, there's no reason that all the code could not be modified to expect 3 or 4 cells per BMS chip but this will require a lot of code changes. And, unfortunately, I'm not going to be able to do this myself because there is such a small market for these oddball modules you're using. So, you'd have to modify the code to expect 3 and 4 and combine them into 7S modules so you can keep track of them properly.

twanek, 2022-12-06:
Thanks for the explanation, this makes thing more clear to me. So, the fact that it detects 2 modules is not a problem at all, this is expected behaviour in this case? Regarding the code adaptation for 7s, I do not think this is big problem, I will use it with a known number of modules and will hardcode all the chip id pairs in the program, so it adds up all 7 cells from the module, etc.

I have few more questions :)

1) just for curiosity, the "standard" 6S modules do have only one chip?

2) what communication protocol is actually used between the Due and the BMS? Sorry if this is a noob question, but:
- if CAN protocol, then why use the strange baud rate and specific TX/RX pins?
- if Serial protocol, then why the CAN library is needed?
this is confusing for me...

3) what about the 2 "extra" temperature readings? The BMS has only 2 temp sensors, but both chip sends 2 different values, totally 4 temperatures? Which one is the real one? It could be that the communication protocol just reads some "extra" addresses from the second chip which is not meant to read? Please take a look at my log file here:
https://github.com/collin80/TeslaBMS/files/10148710/log.for.bms.v02.7s.617647baud.txt

Actually, the 7S modules are very useful for motorhome solar batteries, because with 7s lithium configuration you get a 24v alternator "compatible" pack... My truck alternator outputs 28.8v, so it charges to max 4.11v each cell, which is just perfect. I have (4 tesla modules in parallel configuration).

This way I could connect the starter battery and tesla battery pack together (via a huge current limiting resistor, to protect the alternator not to be shorted by tesla pack). This system works perfectly since 2 years, but I would like to be able to use the built in BMS on the modules.

Thanks!
best regards,

daimlerman, 2023-01-10:
Thank you for all the helpful information. I've got the setup mostly to connect and run reliable.
Collin, you are a Champ!

Closed 2023-01-10.

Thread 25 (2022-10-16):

Random Invalid module response received

Jcr787, 2022-10-16:
Im having these random errors. Errors are not module constant. Im trying to isolate the problem but Im out of Ideas at this point.
I tried changing comms from serial 1 to serial 2 but problem persists. Do you have any idea what could cause this? Here are some examples
2195768 - ERROR: Invalid module response received for module 9  len: 22   crc: 130   calc: 138
2198530 - ERROR: Invalid module response received for module 10  len: 22   crc: 166   calc: 205
2198551 - ERROR: Invalid module response received for module 1  len: 22   crc: 67   calc: 5

It happens more frequent when Im running my LF inverter, not sure if EMI might be the culprit.
Im using a arduino due with direct 3.3v connection, also tried 5v with an bi-directional logic level converter but still get random errors.
I added contactor for precharge and main. Contactors and arduino are powered with a 48v to 12v stepdown converter.

Thanks in advance for your asssitance.

collin80, 2022-10-18:
Yes, it's probably EMI. You're getting the proper number of bytes returned but not the proper CRC so chances are the data has been corrupted. If this only happens every so often you can essentially ignore it. The code knows to discard any traffic that was corrupted so it shouldn't mess anything up. It just means you aren't always getting the latest data.

About all I can suggest is to keep your noisy wires away from the signal wires, if they have to cross it is better to do so perpendicularly, and perhaps shield and/or twist your noisy power wires.

daimlerman, 2022-12-06:
Thanks for responding,  I am having the exact same issue where my 10 boards show up as 20 with different voltage levels.
When combining the displayed voltages for two boards i.e. module 1&2 that would reflect the correct voltage for actual board one.
My setup has 2 groups of  5 parallel modules in series for a 60V system. The problem arising is that the two groups of modules drift apart in voltages. There seems to be a .3 .to .5 of volt difference. How do I balance that? I attached a snippet of a log.
[Info level log.txt](https://github.com/collin80/TeslaBMS/files/10162715/Info.level.log.txt)

Jcr787, 2023-10-11:
Im still dealing with this issue. The lf inverter mosfet switching is causing a ringing noise that get sent thru the battery cables to the modules slave bms. This gets to the UART wires. @collin80 how have you dealt with this before?

collin80, 2023-10-12:
Ah yes, a problem near and dear to all of our hearts. Inverter switching noise is a nasty thing to deal with. There are multiple layers at play here. The Model S modules regenerate traffic at every hop. So, comm becomes clean again at every module and is re-sent fresh to the next in line. This limits the amount of noise that can be coupled. So, the best advice for the wiring near the batteries is to keep it away from your power wires as much as possible. When they come near each other they should do so at right angles if possible. This should limit the amount of noise and every module refreshes the signal so noise is not cumulative.

Long runs of wire would be best if you could shield them or shield the power wires. If at all possible they should not run beside each other parallel. If you have to do that then one or the other or both should be shielded. Ground the shield at one end only to make it into a big antenna to ground. Lastly, the modules run fine at 3.3v but if you can utilize 5v instead you will be better off. The higher the voltage differential between states, the harder it is to corrupt. The official EVTV boards all use 5V signaling down the lines. You can use 3.3v and people have. But, that will be a bit more noise prone. I believe the lowest voltage that works is around 2.7v.

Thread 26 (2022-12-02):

How to change number of cells?

twanek, 2022-12-02:
Hi!

I managed to get some output with a Due, but my modules are S7, not S6  (it is from Mercedes C class).
The problem is, that in your version the number of cells are only up to 6, so I get wrong values for AVG voltages and for one cell voltage it always  reads 0.0V.

Can you please advise, what is needed to change in the code to read all 7 cells? It is enough to change all the "for cycles" to 7, or it needs some additional hex address, etc in the protocol?

Thank you,
best regards!

twanek, 2022-12-04:
Hi again!

I made some more tests, printing detailed info about the module, and there is some strange thing going on:

I have **only one module connected**, but the Due **always finds 2 modules**. Regarding the cell voltages, on the "Pack status" it prints for the "first" module 4 correct values for the cells, then for the "second" module it prints 3 correct values for the rest of the 7 cells of the first module...

Also, for the temperature, AFAIK, the module has only 2 temp sensors, but it prints 4 different temp value, 2 for every "module"...
Attached there is a log file and few photos about the BMS, the version number is readable, so you can understand better what I'm trying to explain. There is only 1 module connected!!!

[log for bms v02, 7s, 617647baud.txt](https://github.com/collin80/TeslaBMS/files/10148710/log.for.bms.v02.7s.617647baud.txt)
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

Can you please look into the log file, what can be the issue, why it finds 2 modules instead of 1?

Thank you!
best regards,

daimlerman, 2022-12-10:
The module in the pictures are definitely from a MB B- class.
Manufacturer module specs are; 2.3KWh of usable energy content; low voltage limit 17.5V; high voltage limit 29V; 308 cells
I am not sure what chemical composition for the cell is, but I would not discharge them below 2.8V (19.6V for the module).

twanek, 2022-12-11:
Thanks for the info!

Indeed has 308 cells, it is a 7s module. I never discharge it under 3.0v, usually 3.1v. Anyway, under 3.1v there is nearly no energy at all, the voltage drops very quickly. We use 4 modules like this in parallel, to power our motorhome.

mart1npetroff, 2025-03-17:
Hello @twanek @collin80 I'm plannig to use this for testing 7s B-class battery as well.
Could you provice me more information if  I need to do any code changes and how to deal with the four values for the two temp sensors?
If you just give me any guidelines I could do the changes and provice PR with the changes.
Thank you.

twanek, 2025-03-17:
Hi!

Its been a while since I worked on this project. Unfortunately, I had to pause the progress, because with 2 kids it is hardly any free-time :) However, I still would like to finish it. Give me few days, will try to review my code, then will share my ideas with you.

twanek, 2025-03-23:
Hi!

My use scenario is 4 modules built in my motorhome, so it is a static environment. For this, my approach would be to hard code the batteryID of each module (actually 2 ID for one module, because there are 2 BMS chips on each module: one reads 4 cells, and one reads 3 cells. Also, the same is for the temp sensors, there are dummy values, you must keep only the correct ones.)

So, for example the first module would consist of ID1 + ID2, second module ID3 + ID4, etc. (hardcoded, thus the program knows which two ID's make one physical module. You read out all the info from the can frame, but then ditching the values from unused cell numbers and temp sensors).

If you work with the same modules all the time like me (and probably most people), this approach should work for you too.

Hope this makes sense.

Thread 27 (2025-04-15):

Тесе тесла BMS

ViktorGys, 2025-04-15:
Здраствуйте! Выдает ошибку:
Due_can.h: Нет такого файла или каталога.
Что делать?

collin80, 2025-04-15:
Sorry I hadn't responded before.

Did you know that I can read Russian? I hope you can read English because my Russian sucks.

You need can_common and due_can from my repos. Then you should be compiling for the Arduino Due (native port). If you want to use a different processor then you would need to either rip out the CAN features or port the code to a different CAN library.

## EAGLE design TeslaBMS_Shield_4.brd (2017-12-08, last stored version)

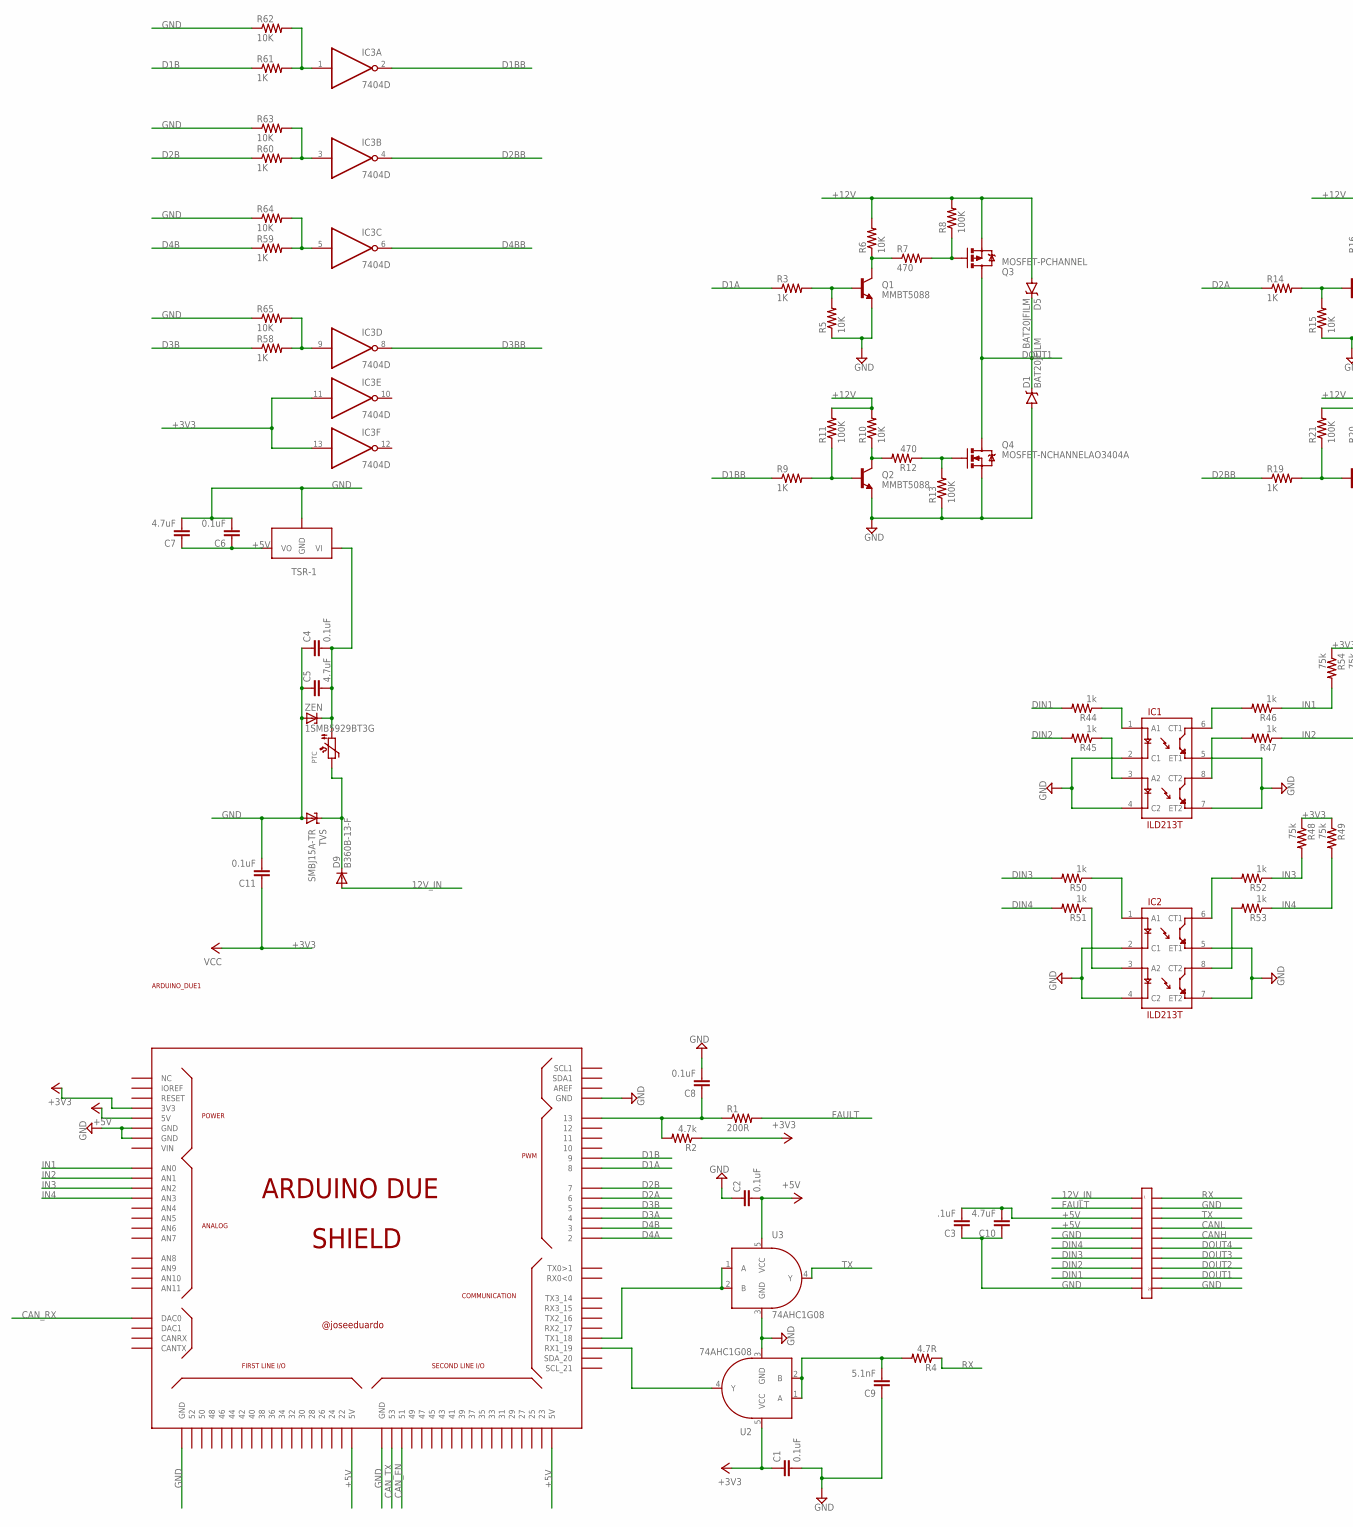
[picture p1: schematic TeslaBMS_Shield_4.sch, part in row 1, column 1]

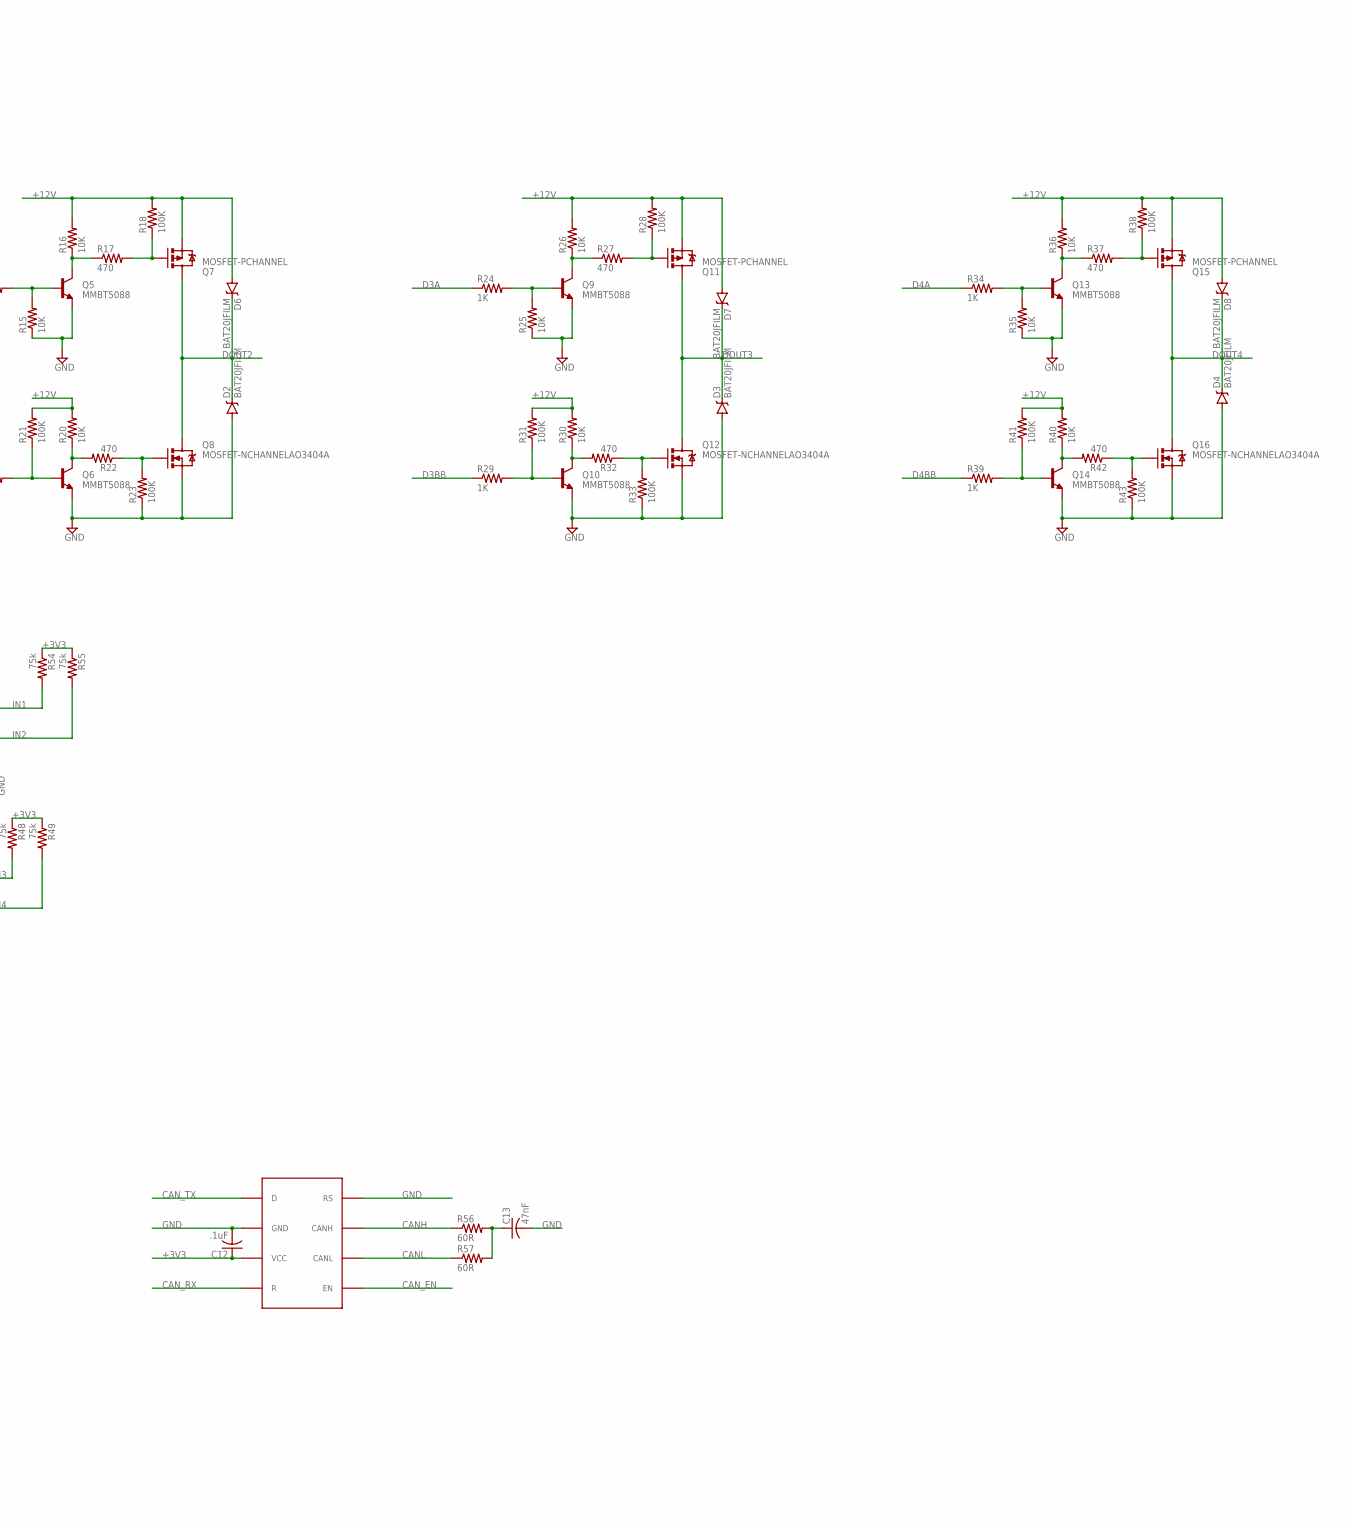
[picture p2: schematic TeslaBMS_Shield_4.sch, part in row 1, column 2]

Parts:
ARDUINO_DUE1: ARDUINO_DUE_SHIELD
C1, C2, C8: 0.1uF; 0603-CAP
C3: .1uF; 0603-CAP
C4, C6, C11: 0.1uF; 0805
C5, C7: 4.7uF; 0805
C9: 5.1nF; 0603-CAP
C10: 4.7uF; 0603-CAP
C12: .1uF; C0603
C13: 47nF; C0805
D1, D2, D3, D4, D5, D6, D7, D8: BAT20JFILM; SOD-323
D9: B360B-13-F; SMB
IC1, IC2: ILD213T; SO08
IC3: 7404D; SO14
PTC: PTC1812
Q1, Q2, Q5, Q6, Q9, Q10, Q13, Q14: MMBT5088; SOT23-3
Q3, Q7, Q11, Q15: MOSFET-PCHANNEL; SOT23-3
Q4, Q8, Q12, Q16: MOSFET-NCHANNELAO3404A; SOT23-3
R1: 200R; 0603-RES
R2: 4.7k; 0603-RES
R3, R9, R14, R19, R24, R29, R34, R39, R58, R59, R60, R61: 1K; 0402-RES
R4: 4.7R; 0603-RES
R5, R6, R10, R15, R16, R20, R25, R26, R30, R35, R36, R40, R62, R63, R64, R65: 10K; 0402-RES
R7, R12, R17, R22, R27, R32, R37, R42: 470; 0402-RES
R8, R11, R13, R18, R21, R23, R28, R31, R33, R38, R41, R43: 100K; 0402-RES
R44, R45, R46, R47, R50, R51, R52, R53: 1k; 0603-RES
R48, R49, R54, R55: 75k; 0603-RES
R56, R57: 60R; M0805
TVS: SMBJ15A-TR; SMBJ
U1: SN65HVD234; SOIC8
U2, U3: 74AHC1G08; SOT353
U9: TSR-1
U$2: VAL-U-LOK-20PIN; VALULOK-20
ZEN: 1SMB5929BT3G; SMB

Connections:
12V_IN: D9.A, U$2.P$1
+3V3: ARDUINO_DUE1.3V3, C1.1, C11.1, C12.1, IC3.11 (I), IC3.13 (I), IC3.14 (VCC), R2.1, R48.1, R49.1, R54.1, R55.1, U1.PIN3 (VCC), U2.5 (VCC)
+5V: ARDUINO_DUE1.5V0 (5V), ARDUINO_DUE1.5V0_1 (5V), ARDUINO_DUE1.5V0_2 (5V), C2.2, C3.2, C6.1, C7.1, C10.2, U3.5 (VCC), U9.P$3 (VO), U$2.P$3, U$2.P$4
+12V: C4.2, C5.2, D5.A, D6.A, D7.A, D8.A, PTC.P$1 (1), Q3.2 (S), Q7.2 (S), Q11.2 (S), Q15.2 (S), R6.2, R8.2, R10.2, R11.2, R16.2, R18.2, R20.2, R21.2, R26.2, R28.2, R30.2, R31.2, R36.2, R38.2, R40.2, R41.2, U9.P$1 (VI), ZEN.C
CANH: R56.1, U1.PIN7 (CANH), U$2.P$15
CANL: R57.1, U1.PIN6 (CANL), U$2.P$14
CAN_EN: ARDUINO_DUE1.51, U1.PIN5 (EN)
CAN_RX: ARDUINO_DUE1.DAC0, U1.PIN4 (R)
CAN_TX: ARDUINO_DUE1.53, U1.PIN1 (D)
D1A: ARDUINO_DUE1.8, R3.1
D1B: ARDUINO_DUE1.9, R61.1
D1BB: IC3.2 (O), R9.1
D2A: ARDUINO_DUE1.6, R14.1
D2B: ARDUINO_DUE1.7, R60.1
D2BB: IC3.4 (O), R19.1
D3A: ARDUINO_DUE1.4, R24.1
D3B: ARDUINO_DUE1.5, R58.1
D3BB: IC3.8 (O), R29.1
D4A: ARDUINO_DUE1.2, R34.1
D4B: ARDUINO_DUE1.3, R59.1
D4BB: IC3.6 (O), R39.1
DIN1: R44.2, U$2.P$9
DIN2: R45.2, U$2.P$8
DIN3: R50.2, U$2.P$7
DIN4: R51.2, U$2.P$6
DOUT1: D1.C, D5.C, Q3.3 (D), Q4.3 (D), U$2.P$19
DOUT2: D2.C, D6.C, Q7.3 (D), Q8.3 (D), U$2.P$18
DOUT3: D3.C, D7.C, Q11.3 (D), Q12.3 (D), U$2.P$17
DOUT4: D4.C, D8.C, Q15.3 (D), Q16.3 (D), U$2.P$16
FAULT: R1.2, U$2.P$2
GND: ARDUINO_DUE1.GND, ARDUINO_DUE1.GND_1 (GND), ARDUINO_DUE1.GND_2 (GND), ARDUINO_DUE1.GND_3 (GND), ARDUINO_DUE1.GND_4 (GND), C1.2, C2.1, C3.1, C4.1, C5.1, C6.2, C7.2, C8.2, C9.1, C10.1, C11.2, C12.2, C13.2, D1.A, D2.A, D3.A, D4.A, IC1.2 (C1), IC1.4 (C2), IC1.5 (ET1), IC1.7 (ET2), IC2.2 (C1), IC2.4 (C2), IC2.5 (ET1), IC2.7 (ET2), IC3.7 (GND), Q1.2 (E), Q2.2 (E), Q4.2 (S), Q5.2 (E), Q6.2 (E), Q8.2 (S), Q9.2 (E), Q10.2 (E), Q12.2 (S), Q13.2 (E), Q14.2 (E), Q16.2 (S), R5.1, R13.1, R15.1, R23.1, R25.1, R33.1, R35.1, R43.1, R62.1, R63.1, R64.1, R65.1, TVS.A, U1.PIN2 (GND), U1.PIN8 (RS), U2.3 (GND), U3.3 (GND), U9.P$2 (GND), U$2.P$5, U$2.P$10, U$2.P$12, U$2.P$20, ZEN.A
IN1: ARDUINO_DUE1.A0 (AN0), R46.1, R54.2
IN2: ARDUINO_DUE1.A1 (AN1), R47.1, R55.2
IN3: ARDUINO_DUE1.A2 (AN2), R48.2, R52.1
IN4: ARDUINO_DUE1.A3 (AN3), R49.2, R53.1
unnamed: D9.C, PTC.P$2 (2), TVS.C
unnamed: ARDUINO_DUE1.19 (RX1_19), U2.4 (Y)
unnamed: ARDUINO_DUE1.18 (TX1_18), U3.1 (A), U3.2 (B)
unnamed: Q1.1 (B), R3.2, R5.2
unnamed: Q3.1 (G), R7.2, R8.1
unnamed: IC1.3 (A2), R45.1
unnamed: ARDUINO_DUE1.13, C8.1, R1.1, R2.2
unnamed: Q1.3 (C), R6.1, R7.1
unnamed: C9.2, R4.2, U2.1 (A), U2.2 (B)
unnamed: Q5.1 (B), R14.2, R15.2
unnamed: Q2.1 (B), R9.2, R11.1
unnamed: Q4.1 (G), R12.1, R13.2
unnamed: Q2.3 (C), R10.1, R12.2
unnamed: Q5.3 (C), R16.1, R17.1
unnamed: Q7.1 (G), R17.2, R18.1
unnamed: Q6.1 (B), R19.2, R21.1
unnamed: Q8.1 (G), R22.1, R23.2
unnamed: Q6.3 (C), R20.1, R22.2
unnamed: Q9.1 (B), R24.2, R25.2
unnamed: Q9.3 (C), R26.1, R27.1
unnamed: Q11.1 (G), R27.2, R28.1
unnamed: Q10.1 (B), R29.2, R31.1
unnamed: Q12.1 (G), R32.1, R33.2
unnamed: Q10.3 (C), R30.1, R32.2
unnamed: Q13.1 (B), R34.2, R35.2
unnamed: Q13.3 (C), R36.1, R37.1
unnamed: Q15.1 (G), R37.2, R38.1
unnamed: Q14.1 (B), R39.2, R41.1
unnamed: Q16.1 (G), R42.1, R43.2
unnamed: Q14.3 (C), R40.1, R42.2
unnamed: IC1.1 (A1), R44.1
unnamed: IC2.6 (CT1), R52.2
unnamed: C13.1, R56.2, R57.2
unnamed: IC3.9 (I), R58.2, R65.2
unnamed: IC3.5 (I), R59.2, R64.2
unnamed: IC2.8 (CT2), R53.2
unnamed: IC1.6 (CT1), R46.2
unnamed: IC1.8 (CT2), R47.2
unnamed: IC3.3 (I), R60.2, R63.2
unnamed: IC3.1 (I), R61.2, R62.2
unnamed: IC2.1 (A1), R50.1
unnamed: IC2.3 (A2), R51.1
RX: R4.1, U$2.P$11
TX: U3.4 (Y), U$2.P$13

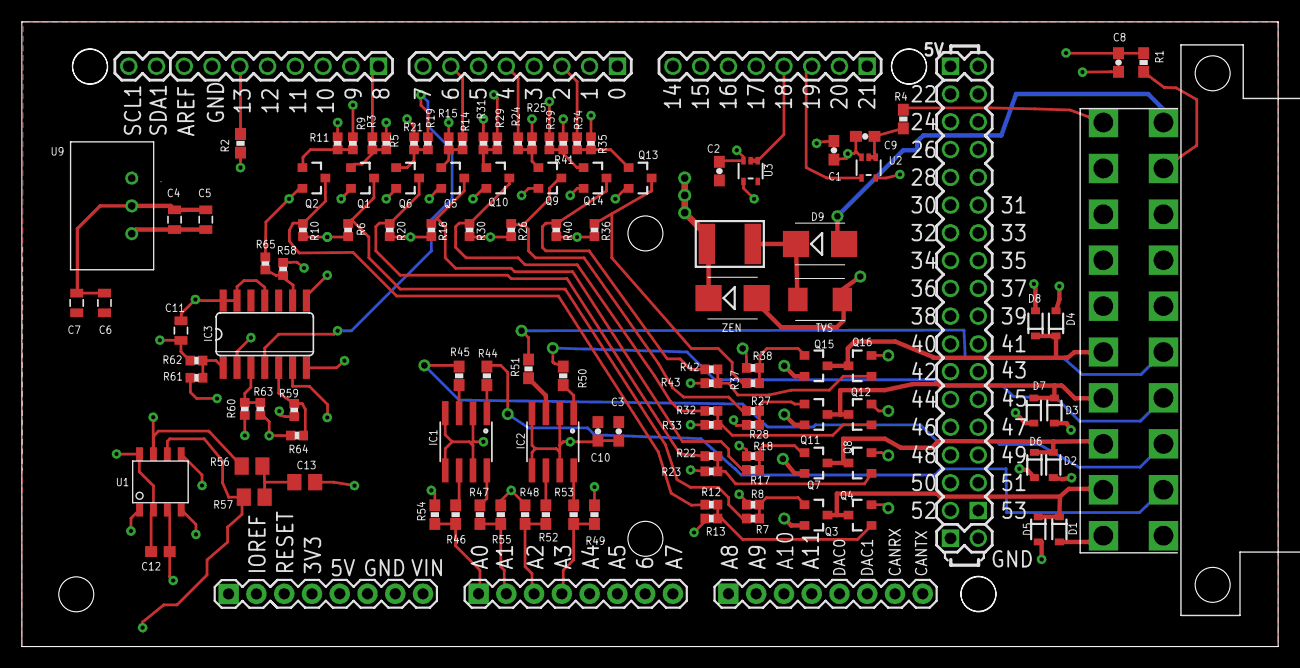
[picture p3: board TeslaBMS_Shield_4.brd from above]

Board: 4 copper layers, 114.9 x 57.1 mm, 115 parts (0 on the bottom side), 79 nets.

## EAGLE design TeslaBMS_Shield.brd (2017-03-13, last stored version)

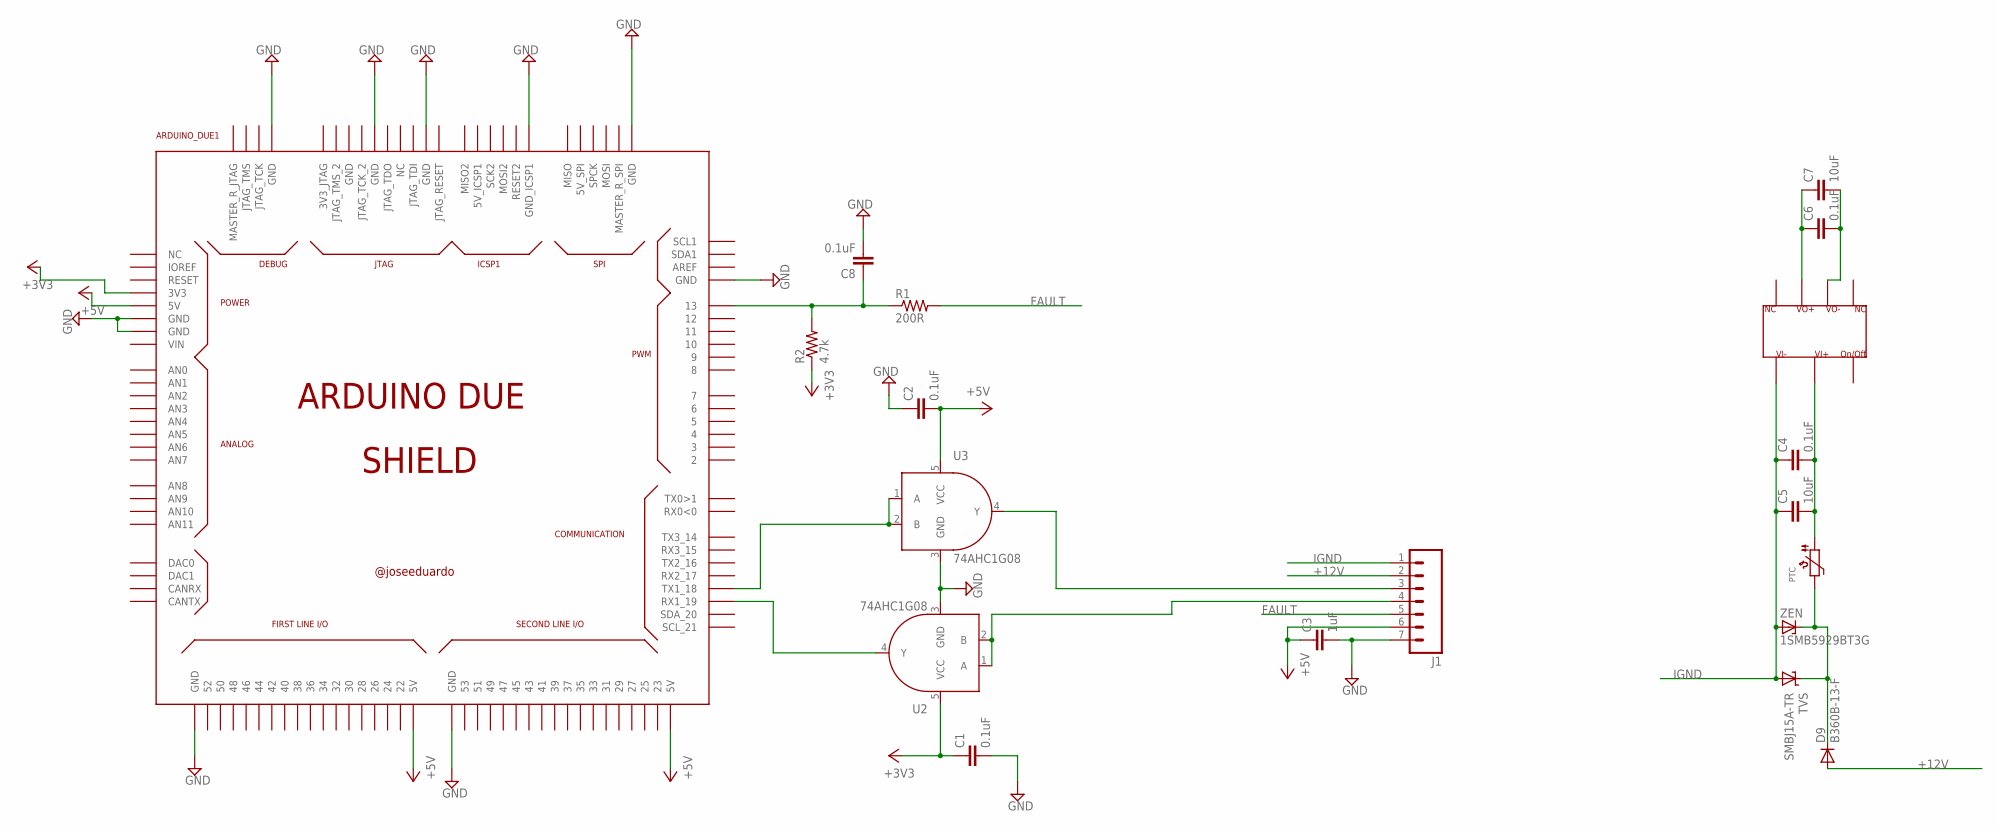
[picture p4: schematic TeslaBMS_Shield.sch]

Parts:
ARDUINO_DUE1: ARDUINO_DUE_SHIELD
C1, C2, C8: 0.1uF; 0603-CAP
C3: 1uF; 0603-CAP
C4, C6: 0.1uF; 0805
C5, C7: 10uF; 0805
D9: B360B-13-F; SMB
J1: M07LONGPADS; 1X07_LONGPADS
PTC: PTC1812
R1: 200R; 0603-RES
R2: 4.7k; 0603-RES
TVS: SMBJ15A-TR; SMBJ
U1: CINCON5V
U2, U3: 74AHC1G08; SOT353
ZEN: 1SMB5929BT3G; SMB

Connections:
+3V3: ARDUINO_DUE1.3V3, C1.1, R2.1, U2.5 (VCC)
+5V: ARDUINO_DUE1.5V0 (5V), ARDUINO_DUE1.5V0_1 (5V), ARDUINO_DUE1.5V0_2 (5V), C2.2, C3.1, C6.1, C7.1, J1.6, U1.P$5, U3.5 (VCC)
+12V: D9.A, J1.2
FAULT: J1.5, R1.2
GND: ARDUINO_DUE1.GND, ARDUINO_DUE1.GND_1 (GND), ARDUINO_DUE1.GND_2 (GND), ARDUINO_DUE1.GND_3 (GND), ARDUINO_DUE1.GND_4 (GND), ARDUINO_DUE1.GND_5 (GND), ARDUINO_DUE1.GND_7 (GND), ARDUINO_DUE1.GND_9 (GND), ARDUINO_DUE1.GND_10 (GND), ARDUINO_DUE1.GND_ICSP1, C1.2, C2.1, C3.2, C6.2, C7.2, C8.2, J1.7, U1.P$6, U2.3 (GND), U3.3 (GND)
IGND: C4.1, C5.1, J1.1, TVS.A, U1.P$1, ZEN.A
unnamed: D9.C, PTC.P$2 (2), TVS.C, ZEN.C
unnamed: ARDUINO_DUE1.19 (RX1_19), U2.4 (Y)
unnamed: ARDUINO_DUE1.18 (TX1_18), U3.1 (A), U3.2 (B)
unnamed: J1.3, U3.4 (Y)
unnamed: J1.4, U2.1 (A), U2.2 (B)
unnamed: C4.2, C5.2, PTC.P$1 (1), U1.P$2
unnamed: ARDUINO_DUE1.13, C8.1, R1.1, R2.2

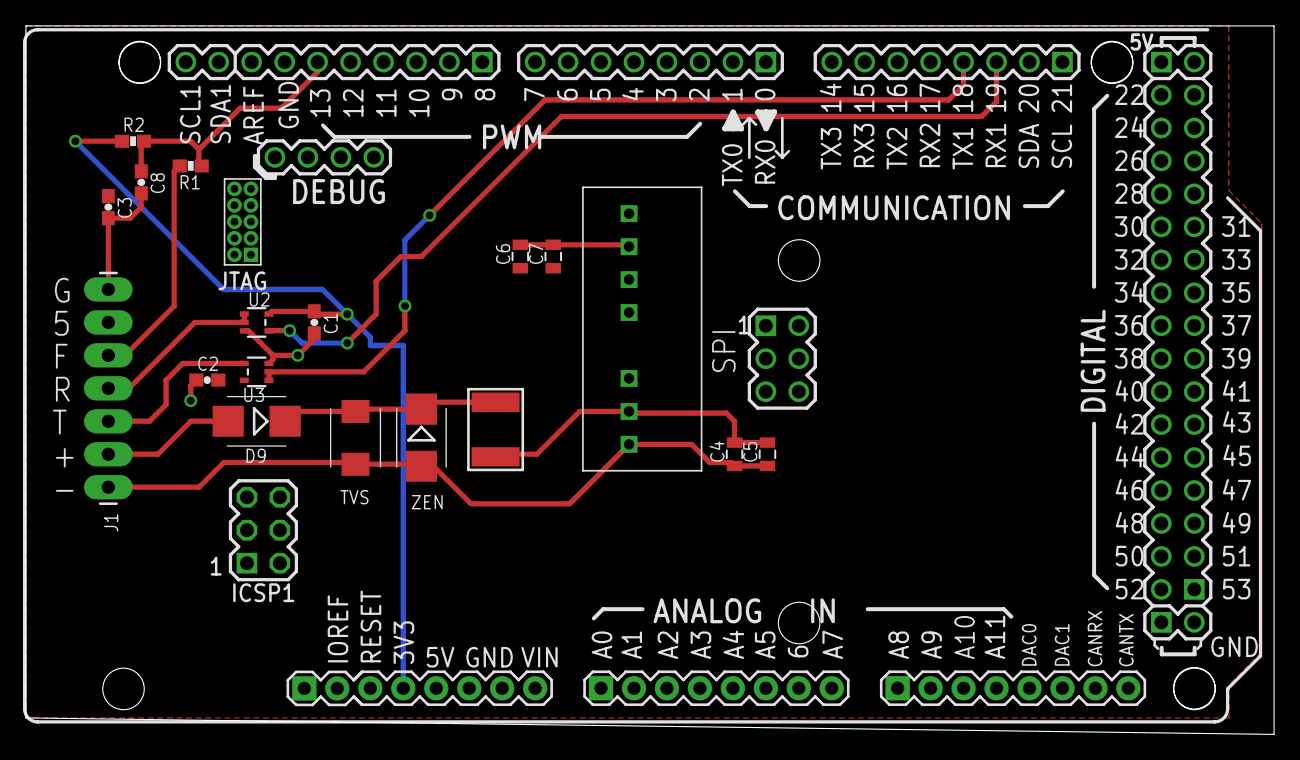
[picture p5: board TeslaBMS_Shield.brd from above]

Board: 2 copper layers, 96.2 x 54.6 mm, 19 parts (0 on the bottom side), 13 nets.

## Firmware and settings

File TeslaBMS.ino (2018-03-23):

#if defined (__arm__) && defined (__SAM3X8E__)
#include <chip.h>
#endif

#include <Arduino.h>
#include "Logger.h"
#include "SerialConsole.h"
#include "BMSModuleManager.h"
#include "SystemIO.h"
#include <due_can.h>
#include <due_wire.h>
#include <Wire_EEPROM.h>

//#define BMS_BAUD  612500
#define BMS_BAUD  617647
//#define BMS_BAUD  608695

BMSModuleManager bms;
EEPROMSettings settings;
SerialConsole console;
uint32_t lastUpdate;

//This code only applicable to Due to fixup lack of functionality in the arduino core.
#if defined (__arm__) && defined (__SAM3X8E__)
void serialSpecialInit(Usart *pUsart, uint32_t baudRate)
{
  // Reset and disable receiver and transmitter
  pUsart->US_CR = UART_CR_RSTRX | UART_CR_RSTTX | UART_CR_RXDIS | UART_CR_TXDIS;

  // Configure mode
  pUsart->US_MR =  US_MR_CHRL_8_BIT | US_MR_NBSTOP_1_BIT | UART_MR_PAR_NO | US_MR_USART_MODE_NORMAL | 
                   US_MR_USCLKS_MCK | US_MR_CHMODE_NORMAL | US_MR_OVER; // | US_MR_INVDATA;

  //Get the integer divisor that can provide the baud rate
  int divisor = SystemCoreClock / baudRate;
  int error1 = abs(baudRate - (SystemCoreClock / divisor)); //find out how close that is to the real baud
  int error2 = abs(baudRate - (SystemCoreClock / (divisor + 1))); //see if bumping up one on the divisor makes it a better match

  if (error2 < error1) divisor++;   //If bumping by one yielded a closer rate then use that instead

  // Configure baudrate including the optional fractional divisor possible on USART
  pUsart->US_BRGR = (divisor >> 3) | ((divisor & 7) << 16);

  // Enable receiver and transmitter
  pUsart->US_CR = UART_CR_RXEN | UART_CR_TXEN;
}
#endif

void loadSettings()
{
    EEPROM.read(EEPROM_PAGE, settings);

    if (settings.version != EEPROM_VERSION) //if settings are not the current version then erase them and set defaults
    {
        Logger::console("Resetting to factory defaults");
        settings.version = EEPROM_VERSION;
        settings.checksum = 0;
        settings.canSpeed = 500000;
        settings.batteryID = 0x01; //in the future should be 0xFF to force it to ask for an address
        settings.OverVSetpoint = 4.1f;
        settings.UnderVSetpoint = 2.3f;
        settings.OverTSetpoint = 65.0f;
        settings.UnderTSetpoint = -10.0f;
        settings.balanceVoltage = 3.9f;
        settings.balanceHyst = 0.04f;
        settings.logLevel = 2;
        EEPROM.write(EEPROM_PAGE, settings);
    }
    else {
        Logger::console("Using stored values from EEPROM");
    }
        
    Logger::setLoglevel((Logger::LogLevel)settings.logLevel);
}

void initializeCAN()
{
    uint32_t id;
    Can0.begin(settings.canSpeed);
    if (settings.batteryID < 0xF)
    {
        //Setup filter for direct access to our registered battery ID
        id = (0xBAul << 20) + (((uint32_t)settings.batteryID & 0xF) << 16);
        Can0.setRXFilter(0, id, 0x1FFF0000ul, true);
        //Setup filter for request for all batteries to give summary data
        id = (0xBAul << 20) + (0xFul << 16);
        Can0.setRXFilter(1, id, 0x1FFF0000ul, true);
    }
}

void setup() 
{
    delay(4000);  //just for easy debugging. It takes a few seconds for USB to come up properly on most OS's
    SERIALCONSOLE.begin(115200);
    SERIALCONSOLE.println("Starting up!");
    SERIAL.begin(BMS_BAUD);
#if defined (__arm__) && defined (__SAM3X8E__)
    serialSpecialInit(USART0, BMS_BAUD); //required for Due based boards as the stock core files don't support 612500 baud.
#endif

    SERIALCONSOLE.println("Started serial interface to BMS.");

    pinMode(13, INPUT);

    loadSettings();
    initializeCAN();

    systemIO.setup();

    bms.renumberBoardIDs();

    //Logger::setLoglevel(Logger::Debug);

    lastUpdate = 0;

    bms.clearFaults();
}

void loop() 
{
    CAN_FRAME incoming;

    console.loop();

    if (millis() > (lastUpdate + 1000))
    {    
        lastUpdate = millis();
        bms.balanceCells();
        bms.getAllVoltTemp();
    }

    if (Can0.available()) {
        Can0.read(incoming);
        bms.processCANMsg(incoming);
    }
}

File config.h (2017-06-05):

#pragma once

#include <Arduino.h>

//Set to the proper port for your USB connection - SerialUSB on Due (Native) or Serial for Due (Programming) or Teensy
#define SERIALCONSOLE   SerialUSB

//Define this to be the serial port the Tesla BMS modules are connected to.
//On the Due you need to use a USART port (Serial1, Serial2, Serial3) and update the call to serialSpecialInit if not Serial1
#define SERIAL  Serial1

#define REG_DEV_STATUS      0
#define REG_GPAI            1
#define REG_VCELL1          3
#define REG_VCELL2          5
#define REG_VCELL3          7
#define REG_VCELL4          9
#define REG_VCELL5          0xB
#define REG_VCELL6          0xD
#define REG_TEMPERATURE1    0xF
#define REG_TEMPERATURE2    0x11
#define REG_ALERT_STATUS    0x20
#define REG_FAULT_STATUS    0x21
#define REG_COV_FAULT       0x22
#define REG_CUV_FAULT       0x23
#define REG_ADC_CTRL        0x30
#define REG_IO_CTRL         0x31
#define REG_BAL_CTRL        0x32
#define REG_BAL_TIME        0x33
#define REG_ADC_CONV        0x34
#define REG_ADDR_CTRL       0x3B

#define MAX_MODULE_ADDR     0x3E

#define EEPROM_VERSION      0x10    //update any time EEPROM struct below is changed.
#define EEPROM_PAGE         0

#define DIN1                55
#define DIN2                54
#define DIN3                57
#define DIN4                56
#define DOUT4_H             2
#define DOUT4_L             3
#define DOUT3_H             4
#define DOUT3_L             5
#define DOUT2_H             6
#define DOUT2_L             7
#define DOUT1_H             8
#define DOUT1_L             9

typedef struct {
    uint8_t version;
    uint8_t checksum;
    uint32_t canSpeed;
    uint8_t batteryID;  //which battery ID should this board associate as on the CAN bus
    uint8_t logLevel;
    float OverVSetpoint;
    float UnderVSetpoint;
    float OverTSetpoint;
    float UnderTSetpoint;
    float balanceVoltage;
    float balanceHyst;
} EEPROMSettings;

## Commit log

2017-02-19 Fix a few bugs, add some notes, add more serial console output.
    [TeslaBMS.ino]
2017-02-19 Fix serial init on Due
    [TeslaBMS.ino]
2017-02-19 A bunch of fixes from tomdebree. Adds better logging functionality as well. Also, source is now easier to adapt to other processors.
    [TeslaBMS.ino]
2017-02-19 Ability to renumber all boards from tomdebree. Fixed up weirdness with array accesses - everything should be consistent now.
    [TeslaBMS.ino]
2017-02-19 Add preliminary balancing support (via tomdebree), fix up more console feedback to be generic.
    [TeslaBMS.ino]
2017-02-19 The max module address is 62 not 63 so code has been corrected. Now max address is a compile time constant.
    [TeslaBMS.ino]
2017-02-19 It's possible to broadcast the reset command so now the renumber function uses a broadcast reset which is a lot simpler.
    [TeslaBMS.ino]
2017-02-21 Fix regression added a few commits back that broke register writes to BMS chip. Change getReply to take a max length so that buffer overflows do not happen.
    [TeslaBMS.ino]
2017-02-22 Preliminary version of a shield to go over an EVTVDue
    [TeslaBMS_Shield.brd, TeslaBMS_Shield.sch]
2017-02-28 Convert temperatures to ratio, show temperatures in debugging info
2017-02-28 Add a lot more configuration related code. Add theoretically necessary code to voltage/temperature retrieval.
2017-03-09 Added canbus output and setup of input
2017-03-13 MANY bug fixes. Recent past versions weren't operable.
    [SerialConsole.cpp, TeslaBMS.ino]
2017-03-13 Added a prettier status screen, some code fixes
    [TeslaBMS_Shield.brd, TeslaBMS_Shield.sch]
2017-03-14 More bug fixing to make things more reliable. Some tweaking of visuals. Addition of fault status output
    [TeslaBMS.ino]
2017-03-14 Tweaked temperature calculations to be seemingly more accurate. Added fault and alert listing on pack status screen
2017-03-14 Switched from third order approximation to steinhart-hart equation for temperatures. So far, it seems better.
2017-03-15 Added a detailed pack screen with all cell voltages and module temperatures
2017-05-01 Added system IO code for new boards
    [TeslaBMS_Shield_2.brd, TeslaBMS_Shield_2.sch]
2017-06-04 Source reformatting, fixed cell balancing, implemented hysteresis for balancing
    [TeslaBMS_Shield_2.brd, TeslaBMS_Shield_2.sch]
2017-06-05 Inputs are out of order on board so here's a header change to correct that in software.
    [TeslaBMS.ino, config.h]
2017-12-08 Add more versions of board
    [TeslaBMS_Shield_2.brd, TeslaBMS_Shield_2.sch, TeslaBMS_Shield_3.brd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]
2018-02-18 Update readme file
    [TeslaBMS_Shield.brd, TeslaBMS_Shield.sch, TeslaBMS_Shield_2.brd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]
2018-03-23 Track good vs bad packets and allow for baud rate changing more easily.

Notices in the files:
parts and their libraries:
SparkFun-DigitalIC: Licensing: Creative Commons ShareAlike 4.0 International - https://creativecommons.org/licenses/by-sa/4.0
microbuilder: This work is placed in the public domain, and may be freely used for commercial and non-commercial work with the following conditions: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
